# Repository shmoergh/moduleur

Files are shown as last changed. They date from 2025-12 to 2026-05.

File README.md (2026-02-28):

# Shmøergh Moduleur

A fully analog, DIY-friendly modular synthesizer system derived from the original [Shmøergh Hog](https://www.shmoergh.com/hog). The instrument is built from discrete modules — oscillators, filters, VCAs, utilities, and a digital Brain — usable either in their default pre-patched configuration or in any Eurorack system.

The project targets builders who want a reproducible, open, and hackable analog instrument. All circuits, PCBs, firmware, and mechanical designs are published here, including schematics, Gerbers, BOMs, and panel files. Each module is self-contained and can be assembled or modified independently.

Moduleur follows standard Eurorack conventions (±12 V rails, reverse polarity protection, 10-pin power, 1 V/oct where applicable). Designs emphasize robustness, available components, and clear signal flow. Simulation files and test notes are included for further study or modification.

This repository reflects ongoing hardware and firmware development, and module revisions may change over time.

Follow progress at [shmoergh.com](https://www.shmoergh.com/moduleur/)

moduleur-bp
moduleur-bp

## Community

Join the [Shmøergh Discord server](https://discord.gg/CAynJwSkaW).

## Building

[Read the build guide &rarr;](https://github.com/shmoergh/moduleur/wiki)

## Modules

- [Power supply](https://github.com/shmoergh/moduleur/tree/main/modules/01-psu)
- [VCO](https://github.com/shmoergh/moduleur/tree/main/modules/02-vco)
- [Mixer + sidechain compressor](https://github.com/shmoergh/moduleur/tree/main/modules/03-sidechain-mixer)
- [VCF](https://github.com/shmoergh/moduleur/tree/main/modules/04-vcf)
- [ADSR & VCA](https://github.com/shmoergh/moduleur/tree/main/modules/05-adsr-vca)
- [Analog Bitcrusher / S&H + LFO + Output](https://github.com/shmoergh/moduleur/tree/main/modules/06-utils-output)
- [Brain](https://github.com/shmoergh/moduleur/tree/main/modules/07-brain)
- [Default patch](https://github.com/shmoergh/moduleur/tree/main/modules/08-default-patch)

## Enclosure

- [Moduleur enclosure by Shmøergh](https://github.com/shmoergh/moduleur/tree/main/enclosure)
- [Eurorack frame](https://github.com/shmoergh/moduleur/tree/main/eurorack/frame)
- [Eurorack faceplates](https://github.com/shmoergh/moduleur/tree/main/eurorack/faceplates)

## Roadmap

We're working on improving modules, and adding firmwares to Brain as we go. You can see our loosely held ideas in the [Roadmap](./ROADMAP.md) file.

## Contribution & Bug Reports

Contributions are much appreciated, especially in areas where community experience can improve the reliability and longevity of the system.

[Contributing guidelines](./CONTRIBUTING.md)

## License

Shmøergh Hog Moduleur © 2025

Hardware is licensed under [CC BY-NC 4.0](https://creativecommons.org/licenses/by-nc/4.0/)

Software is licensed under [MIT](https://opensource.org/license/mit).

Font used on PCBs: https://departuremono.com

Simulations made in [CircuitJS](https://www.falstad.com/circuit/circuitjs.html)

## ⚠️ Build Smart

Moduleur is an open-source DIY electronics project intended for experienced builders.

Although it operates from low-voltage DC power, incorrect assembly, wiring, or component selection can result in equipment damage or safety risks.

By building this project, you accept full responsibility for safe assembly and operation.

Please read the full safety notice and disclaimer before proceeding:

👉 [Safety & Intended Use](SAFETY.md)

👉 [Full Disclaimer](DISCLAIMER.md)

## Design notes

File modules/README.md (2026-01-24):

# BEFORE YOU BUILD

👉 Make sure you read the full [build guide](https://github.com/shmoergh/moduleur/wiki) thoroughly before you start building the Moduleur.

# BOM

Each module has a dedicated BOM. We also created a full BOM if you want to order all modules at once:

- [Full BOM](https://docs.google.com/spreadsheets/d/1Qo4ZxYgp-tBQ1XDLqPfu5fhcQhO-8mitsnlWUWIVU-8/edit?usp=sharing) — Contains only the BOM for the modules. For the enclosure, check the [enclosure BOM](https://github.com/shmoergh/moduleur/blob/main/enclosure/enclosure-bom.csv).
- [Mouser cart](https://www.mouser.com/Tools/SavedCart/Share?AccessID=7d2d54395b) — Last update: 24 Jan 2026

---

### Recommended build order

1. [PSU](https://github.com/shmoergh/moduleur/tree/main/modules/01-psu)
2. [VCO](https://github.com/shmoergh/moduleur/tree/main/modules/02-vco)
3. [Mixer & sidechain compressor](https://github.com/shmoergh/moduleur/tree/main/modules/03-sidechain-mixer)
4. [VCF](https://github.com/shmoergh/moduleur/tree/main/modules/04-vcf)
5. [ADSR & VCA](https://github.com/shmoergh/moduleur/tree/main/modules/05-adsr-vca)
6. [Utils + Output](https://github.com/shmoergh/moduleur/tree/main/modules/06-utils-output)
7. [Brain](https://github.com/shmoergh/moduleur/tree/main/modules/07-brain)
8. [Default Patch](https://github.com/shmoergh/moduleur/tree/main/modules/08-default-patch)

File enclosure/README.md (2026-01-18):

# Shmøergh Moduleur / DIY Enclosure

## BOM

See [enclosure-bom.csv](enclosure-bom.csv) for the complete bill of materials.

## Build guide

See [Enclosure build guide &rarr;](https://github.com/shmoergh/moduleur/wiki/Enclosure-design)

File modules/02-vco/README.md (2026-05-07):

# Shmøergh Moduleur / VCO

Eurorack compatible VCO for the Shmøergh Moduleur.

## Features

- Raw saw generator with classic waveshaper circuits. Triangle, saw and square outputs
- Sub oscillator and noise circuit (can be selected with a jumper)
- Pulse width voltage control for square wave
- Precision for about 7 octaves
- Hard sync input
- FM input
- Two temperature compensation options for flexible DIY build (one is THT only)
- Designed from very common electronic components

## Boards

- [Core board](./electronics/core/) — Contains all active circuitry and handles the complete audio, CV, and logic processing for the module.
- [UI board](./electronics/ui/) — Hosts all panel-mounted controls and connectors, providing the physical interface to the module’s Core PCB.

## How to build

[**Follow the build guide &rarr;**](https://github.com/shmoergh/moduleur/wiki)

<br>

## Module specific instructions

### Q3 vs Q4 transistor (J111)

As commented on the Core board, **you only need either Q3 or Q4**: if you got Q4 assembled by JLCPCB then do not solder Q3. The J111 JFET is not a super-common component and sometimes it's out of stock at JLCPCB — to prepare for the potential shortage we added a THT footprint too so you can source and solder it manually easily.



### D4 & D5 diodes

These diodes are supposed to clamp the pulse width modulation signal so that it stays withing audible range. You can skip these, they're here for legacy reasons and will be removed in the next version.

CleanShot 2026-04-26 at 06 59 10@2x

### Temperature compensation

All analog VCOs have a way to compensate temperature drifts. You can read about the background of this in this fantastic series of posts on Xonik.no: [part 1](https://www.xonik.no/theory/vco/expo_converter_1.html), [part 2](https://www.xonik.no/theory/vco/expo_converter_2.html), [part 3](https://www.xonik.no/theory/vco/reference_current.html).

We had quite some trouble in the past finding components for temperature compensation (the classic tempco resistors are almost impossible to obtain). So we designed the Moduleur VCO in a way that there are two ways for temperature compensation, **but you need to build only one of them**.

CleanShot 2025-12-15 at 21 54 36@2x

#### Option 1: Using a PTS120601B100RP100 temperature sensor
The PTS1206 is an SMD component so be prepared with your soldering skills. For this the following resistors and trimmers should be soldered (find these in the KiCAD file):

- R_FB: 91kΩ resistor
- R_W1: 20kΩ multiturn trimmer pot
- R_D1: short (with a piece of wire)
- TH1: do not place component
- R_D2: 6.2kΩ (50PPM) resistor
- R_D3: 4.22Ω (50PPM) resistor
- TH2: PTS120601B100RP100 (https://mou.sr/4g7SsGi) temperature sensor
- R_W2: do not place component

Here's the equivalent network of the temperature compensation if you're using PTS120601B100RP100:

CleanShot 2026-04-26 at 06 47 58@2x

#### Option 2: Using a NTCLE203E3103FB0 NTC thermistor
This is a through hole component, very widely available. For this setup, you need to use the following values/components:

- R_FB: 22kΩ resistor
- R_W1: short (with a piece of wire)
- R_D1: 11kΩ resistor
- TH1: NTCLE203E3103FB0 (https://mou.sr/4nM5nSy)
- R_D2: 27kΩ resistor
- R_D3: 2.7kΩ resistor
- TH2: do not place component
- R_W2: 500Ω trimmer

CleanShot 2026-04-26 at 06 49 45@2x

**Which one should you choose?**
The two setups are almost identical but **option 1** (using the PTS) is a little bit more accurate. If you can solder SMD components and you have a bit more budget then we recommend that option.

**Temperature compensation component help**

To make soldering a bit easier, the alternate names of the temp.co. components are marked on the PCB:



### Tuning

You'll need to tune the wave shapes and the oscillator frequency to be musically in tune.

#### Tuning the wave shapes

First we'll set the correct bias to all waveforms as well as the shape of the triangle wave. There are two trimmers you'll need to use: RV_SAW_BIAS1 ("SAW BIAS" on the Core board silkscreen), and RV_TRI_BIAS1 ("TRI BIAS" on the board.). You'll need an oscilloscope for this.

1. Connect the oscilloscope to the Triangle output. Make sure your oscilloscope is in DC coupling.
2. The triangle is generated from the sawtooth wave. In order to have a nice symmetric triangle you need to adjust the saw bias. Use the SAW BIAS trimmer to adjust the symmetry of the Triangle waveshape (and implicitly the bias of the saw wave).
3. The triangle now should be symmetric but most likely not centered around 0V. To move it on the Y axis, use the TRI BIAS trimmer.

You should be good once the triangle output is:

- A nice triangle
- Oscillates around 0V



#### Frequency tuning

As with all analog VCO you need to go through a tuning process to make sure it tracks with 1V/octave. Here's how:

0. Turn the Octave (main tune) knob all the way down and the Fine tune knob in the middle.
1. Connect a keyboard with CV output to the VCO. We recommend an Arturia Keystep, Beatstep Pro, Korg SQ1 or similar. Or if you have the [Brain module](https://github.com/shmoergh/moduleur/tree/main/modules/07-brain) done, you can use [Le Controlleur](https://github.com/shmoergh/le-controlleur) firmware in MIDI mode and a MIDI keyboard too.
2. Turn HI-FREQ pot all the way down: play a very high pitch note on the keyboard and turn the knob until the pitch stops going down.
3. Play C1 on keyboard. Use the BIAS trimmer to set the frequency to C1 (32.703Hz)
4. Play C4 and use BIAS trimmer to set the frequency to C4 (261.63Hz)
5. Play C1 and use WIDTH trimmer to tune it to 32.703Hz
6. Loop steps 3 + 4
7. When C1 and C4 are in tune, play C7 and use the HI-FREQ trimmer to make up the pitch for higher frequencies.
8. Go back to step 3 & 4 to adjust tuning for lower frequencies, then go to step 6 again, until you get to a reasonable end result.

Note that the VCO is limited to about 7-8 octaves. Beyond that, expect the pitch to drift.

### Normalization

`JP2` and `JP3` jumpers on the UI board connect CV and FM to GND respectively to avoid noise on these inputs. They are used for Eurorack use normalization if needed.

👉 **IMPORTANT:** If you're using the default patch board, DO NOT connect these jumpers otherwise your CV inputs will be tied to GND all the time resulting in pitch CV not working on one or both of the VCOs.

CleanShot 2026-03-30 at 10 14 48@2x

<br>

## License

Open source licensed under [CC BY-NC 4.0](https://creativecommons.org/licenses/by-nc/4.0/).

Feel free to fork, build, and tweak.

[Disclaimer](https://github.com/shmoergh/moduleur/blob/main/DISCLAIMER.md)

## Latest module version

v1.0

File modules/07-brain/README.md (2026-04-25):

# Shmøergh Moduleur / Brain

Brain is a universal digital module for the Shmøergh Moduleur which enables the development of new functions like sequencers, MIDI features, digital voices and synths and whatever comes to mind. The module uses a Raspberry Pi Pico / Pico 2 so all features of the board are available in any language (Micropython, C++, Rust). To speed up development we provide an SDK that makes it easy to use the available pots, buttons, I/O and MIDI.

## FIX LOG

‼️ IF YOU ARE NOT BUILDING FROM THE LATEST PCB REVISION IN THIS REPOSITORY, PLEASE CHECK THE [FIX LOG](FIXLOG.md) (PCB ERRATA) BEFORE STARTING, AS EARLIER REVISIONS MAY CONTAIN ISSUES THAT REQUIRE CORRECTION.

## Features

- Universal digital module based on Raspberry Pi Pico or Pico 2
- Three buttons, one of them with LED
- Two potmeters
- Dedicated MIDI input with input protection
- Six dimmable LED indicators
- Two audio or CV inputs
- Two audio or CV outputs
- One pulse input
- One pulse output
- USB-C connector
- Uses an actual Rpi Pico board under the hood
- Brain SDK for all UI components
- CV voltage output tuner trimmer pot
- Software based AC/DC coupling on audio/CV output
- Separate UI & core PCBs for reusability
- 12HP Eurorack compatible design
- Reverse polarity protection

## Programs

&rarr; [Brain firmwares](https://github.com/shmoergh/brain-firmwares)

## Boards

- [Core board](./electronics/core/) — Contains all active circuitry and handles the complete audio, CV, and logic processing for the module.
- [UI board](./electronics/ui/) — Hosts all panel-mounted controls and connectors, providing the physical interface to the module’s Core PCB.

## How to build

[**Follow the build guide &rarr;**](https://github.com/shmoergh/moduleur/wiki)

<br>

## Module specific instructions

### Soldering the Raspberry Pi Pico board

You can solder the Pico to the Core board directly or using pin headers. If you solder directly then you'll need a very thin USB cable to be able to connect to the original micro USB port of the Pico.

### USB-C connection — EXPERIMENTAL

As it's listed on page 7 of the [Pico data sheet](https://pip-assets.raspberrypi.com/categories/610-raspberry-pi-pico/documents/RP-008307-DS-1-pico-datasheet.pdf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), you can use the test points on the Pico board to connect to its USB, as well as control the BOOTSEL button remotely. This allowed us to add an USB-C connection and a dedicated BOOTSEL button, available without taking the enclosure backplate off.

**To use the external USB-C connector and BOOTSEL button, you'll need to connect the Pico's TP1, TP2, TP3 and TP6 test points to dedicated pins of the USB-C and Bootsel button on the Brain's Core board.**

To do this, you have two options:



**Option 1:**
- Solder the Pico to the Brain Core **using pin headers**. The point is to leave some gap between the Pico and the Brain Core board so that you can lead **wires** through the hole in the center of the Core board to connect up the Pico's TP1, TP2, TP3 and TP6 (BOOTSEL) testpoints:



**Option 2:** You can also use pin headers and sockets to connect the Pico to the Core board — this way you can take replace the Pico board in the future, if you need to for some reason. Make sure you use low profile sockets and matching headers in this case, otherwise if you're building for the Moduleur enclosure, the brain module won't fit the height of the case. (Example [socket](https://mou.sr/48U4sKo) and [header](https://mou.sr/4p6XDd6) — Note: this is UNTESTED)

**Option 3:** Solder the Pico directly to the Core board directly and _solder through_ the dedicated TP1, TP2, TP3 and TP6 plated holes. If you choose this option, make sure you solder the Pico to the bottom side of the Core board like shown here:



⚠️ **NOTE — So far only Option 1 is tested.**

## Calibrating the CV outputs
The DAC outputs of the Brain module directly generate up to 4095 mV. These are amplified to 0–10 V — to match Eurorack voltage ranges — by the U4A and U5A op-amps. Because the output stage isn't built around precision components, every assembled Brain has small differences in gain and offset that need to be tuned out before the CV outputs can be trusted for pitch tracking or anything else that demands accuracy.

**Calibration happens in two stages, in this order:**

### 1. Hardware calibration

Adjusts the trimmers `RV_CV_GAIN1` and `RV_CV_GAIN2` that sets the overall gain of the output stages. The goal is to get roughly 1 V per step across the output range. This is a coarse, mechanical adjustment — turn a screw, watch a multimeter — and you typically only do it once per board (or again after any rework on the output op-amps or trimmers).

Use the [Brain diagnostics firmware](https://github.com/shmoergh/brain-diagnostics) for this. Flash it onto the Brain, press Button A to advance to Test 14 (CV output hardware-trimmer calibration), and follow the procedure in that repo's README. 

### 2. Software calibration

Once the analog gain is roughly right, software calibration compensates for the residual drift of op-amp offsets, DAC non-linearity, and the small per-step error that the trimmer can't reach. The result is a calibration table stored in a reserved sector of the Pico's flash. Firmwares **built on the Brain SDK** can load this table on boot and apply it to their CV outputs.

Use the [Brain CV tuner firmware](https://github.com/shmoergh/brain-cv-tuner) for this. Flash it onto the Brain after hardware calibration is done, follow its README to step through and measure each whole-volt point, and the resulting table gets written on the Pico board. Once that's done, you can flash your real firmware back; the calibration data survives subsequent flashes as long as the firmware uses the Brain SDK and reserves the storage sectors at link time (see the Brain SDK's ["Preserving calibration data"](https://github.com/shmoergh/brain-sdk/blob/main/docs/PRESERVING_CV_CALIBRATION.md) doc to learn more).

The order matters. If you run software calibration first and then turn the hardware trimmer, the software calibration numbers become stale and you'll have to redo them. Always trim the hardware first, then run software calibration on top.

After both stages, the Brain's CV outputs will hit the asked-for voltage to within a fraction of a millivolt across the full range — accurate enough for 1 V/octave pitch tracking and any other CV use you care about.

## Development with Picoprobe

The most efficient and probably the cheapest way to develop firmware for the brain is to use a second Pico board as a debug probe, as described in the [official documentation](https://pip-assets.raspberrypi.com/categories/610-raspberry-pi-pico/documents/RP-008276-DS-1-getting-started-with-pico.pdf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) (from page 17). To connect up the PicoProbe board to the Pico on the Core board you need to solder pin headers to the Pico board's DEBUG connections (SWCLK, GND, SWDIO) and also use the J_DEV1 pin header, which is directly connected to the UART RX and TX on pins 1 and 2. If you're housing the Brain module in the Moduleur enclosure we recommend (1) using right angle pin headers and (2) soldering the Pico board's DEBUG headers _oriented to the inside_ of the board, so it fits the space:

picoprobe

<br>

## Firmware development with the Brain SDK

The Brain SDK is a firmware and library collection for the Raspberry Pi Pico/Pico 2, designed to speed up the development. It provides reusable components for I/O, UI, DSP, and more, along with example programs and scripts to streamline project setup and prototyping.

[Brain SDK](https://github.com/shmoergh/brain-sdk)

## License

Open source licensed under [CC BY-NC 4.0](https://creativecommons.org/licenses/by-nc/4.0/).

Feel free to fork, build, and tweak.

[Disclaimer](https://github.com/shmoergh/moduleur/blob/main/DISCLAIMER.md)

## Latest module version

v1.1

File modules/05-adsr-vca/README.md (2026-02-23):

# Shmøergh Moduleur / ADSR + VCA

A combined, Eurorack compatible envelope generator and voltage controlled amplifier module for the Shmøergh Moduleur.

## FIX LOG

‼️ IF YOU ARE NOT BUILDING FROM THE LATEST PCB REVISION IN THIS REPOSITORY, PLEASE CHECK THE [FIX LOG](FIXLOG.md) (PCB ERRATA) BEFORE STARTING, AS EARLIER REVISIONS MAY CONTAIN ISSUES THAT REQUIRE CORRECTION.

## Features

- Combines a full ADSR envelope generator and VCA module in one
- Envelope times go up until 10sec (depending on the used pot values)
- The ADSR output can be normalized to the CV of the VCA
- Bias trimmer for VCA to set base amp level
- LED indicator for envelope
- 12HP Eurorack compatible design
- Reverse polarity protections

## Boards

- [Core board](./electronics/core/) — Contains all active circuitry and handles the complete audio, CV, and logic processing for the module.
- [UI board](./electronics/ui/) — Hosts all panel-mounted controls and connectors, providing the physical interface to the module’s Core PCB.

## How to build

[**Follow the build guide &rarr;**](https://github.com/shmoergh/moduleur/wiki)

<br>

## Module specific instructions

### Setting the envelope output voltage

You can set the [maximum] output voltage of the envelope using the RV_OUT_GAIN1 trimmer on the Core board. Recommended value is 8V.

### Setting the base volume of the VCA

1. Plug in a VCO to the VCA input
2. Connect the output of the VCA to an oscilloscope. Alternatively you can also connect it to the input of the Output module
3. Use the RV_VCA_BIAS2 trimmer to set turn down the volume of the VCA just so that there's nothing on the output. This will make the VCA work in a way that even the smallest control voltages will cause audible gain increase without any crosstalk.

### What if I have crosstalk?

It's likely that you need to turn down the base volume of the VCA using the RV_VCA_BIAS2 trimmer on the Core board.

### Defaulting the ADSR output to VCA CV input

It's a very common way to use an ADSR together with a VCA. To save on cables you can default the ADSR's output to the VCA's CV input by shorting the JP_DEFAULT_ENV_TO_VCA1 jumper.

### R1 resistor should be a short

As marked in the schematics, in the current version the R1 resistor is included for testing/experimental purposes only. You need to short this connection:



## License

Open source licensed under [CC BY-NC 4.0](https://creativecommons.org/licenses/by-nc/4.0/).

Feel free to fork, build, and tweak.

[Disclaimer](https://github.com/shmoergh/moduleur/blob/main/DISCLAIMER.md)

## Latest module version

v1.2

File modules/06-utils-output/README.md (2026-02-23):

# Shmøergh Moduleur / Utils & Output

Combined analog bitcrusher, LFO and an output interface with overdrive in a single Eurorack compatible module.

## FIX LOG

‼️ IF YOU ARE NOT BUILDING FROM THE LATEST PCB REVISION IN THIS REPOSITORY, PLEASE CHECK THE [FIX LOG](FIXLOG.md) (PCB ERRATA) BEFORE STARTING, AS EARLIER REVISIONS MAY CONTAIN ISSUES THAT REQUIRE CORRECTION.

## Features

- Analog bitcrusher
- External trigger of analog bitcrusher, which allows sample & hold usage
- Analog LFO with square and triangle output
- LFO works from about 0.1Hz to 200Hz audio range
- LED indicator for LFO
- Output module to interface line level audio
- LED based overdrive in output module
- Optional dual-mono headphones output
- 12HP Eurorack compatible design
- Reverse polarity protection

## Boards

- [Core board](./electronics/core/) — Contains all active circuitry and handles the complete audio, CV, and logic processing for the module.
- [UI board](./electronics/ui/) — Hosts all panel-mounted controls and connectors, providing the physical interface to the module’s Core PCB. 

## How to build

[**Follow the build guide &rarr;**](https://github.com/shmoergh/moduleur/wiki)

<br>

## Module specific instructions

### LFO pot value

The range of the LFO depends on the value of the frequency pot. The recommended pot value goes from 200kΩ (higher minimum frequency) to 1M (lower minimum frequency). We recommend using a logarithmic pot so that you have more control on low frequencies. We found the sweet spot by using a 500kΩ pot.

### Setting the minimum LFO frequency

In order to charge the main cap of the LFO you'll need to make sure there's _some_ input current on the integrator (U201B). This is the role of the R206 resistor. The lower the value of this resistor the lower frequencies you can achieve with the LFO. Too low values however can make the output latch, we found the sweet spot at around 220Ω.

### Setting the maximum output level

1. Turn drive all the way down
2. Use RV_LINE_OUT_LVL1 trimmer on the Core board to set the maximum output level. You typically want to set it so that it works well with external gear on line level. [More info about line level values](https://en.wikipedia.org/wiki/Line_level)

### Selecting between line out or headphones out

You can use the main output to connect to line out or headphones out using the JP1 jumper on the Core board.

**⚠️ Use stereo cable on the output if you're using headphones** The output is dual-mono, which means that the right and left channel are connected. If you use a mono cable for the output then you'll esentially ground both output channels.

<br>

## Photos



## License

Open source licensed under [CC BY-NC 4.0](https://creativecommons.org/licenses/by-nc/4.0/).

Feel free to fork, build, and tweak.

[Disclaimer](https://github.com/shmoergh/moduleur/blob/main/DISCLAIMER.md)

## Latest module version

v1.1

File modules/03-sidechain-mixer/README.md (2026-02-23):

# Shmøergh Moduleur / Sidechain Mixer

4 channel Eurorack compatible mixer with sidechain compressor.

## Features

- 4 input audio or CV mixer (DC coupled)
- Channel 4 can be used as the control input for a VCA based sidechain compressor that acts on the output mix. Channel 4 can be individually added to the output mix or can remain silent, while the compressor still operates.
- Gain control for channel 4 which allows to amplify line level signals to Eurorack level, allowing to mix external instruments with Eurorack sound sources
- Dedicated output volume control
- Separate core and UI PCBs for reusability and custom UI builds
- Gerber files for JLCPCB order
- Designed from very common electronic components

## Boards

- [Core board](./electronics/core/) — Contains all active circuitry and handles the complete audio, CV, and logic processing for the module.
- [UI board](./electronics/ui/) — Hosts all panel-mounted controls and connectors, providing the physical interface to the module’s Core PCB.

## How to build

[**Follow the build guide &rarr;**](https://github.com/shmoergh/moduleur/wiki)

<br>

## Module specific instructions

### Core circuit block diagram



**How does it work?**

1. INPUT 1-3 is mixed with a DC coupled mixer. The output is inverted.
2. The output of the INPUT 1-3 mixer goes in the audio input of a VCA.
3. INPUT 4 goes in an amp which enables amplifying the [audio] signal from line level to Eurorack level if needed.
4. The gained INPUT 4 goes in a peak detector
5. The output of the peak detector goes in a subtractor (comparator) circuit. This generates a _negative_ control voltage if the peak volume of the audio signal is above a certain threshold (ie. the peak audio signal goes in the `-` input of the subtractor circuit and the threshold [pot] voltage goes in the `[+]` input).
6. The output of the subtractor is used as the control voltage of the VCA. A diode in reverse polarity makes sure that only negative control voltages are "accepted" on the CV input of the VCA, resulting in gain reduction.
7. The output of the VCA goes in a the (output) inverting mixer. This way INPUT 1-3 is inverted back to normal polarity.
8. In order to be able to use INPUT 4 as a regular channel on the mixer, the [gained] INPUT 4 goes through an inverter and then in the output mixer (which inverts it back to normal polarity). Because the gained INPUT 4 is mixed in the final output mixer you can mix line level things with the Moduleur voices.

Some notes:

### Stereo VS mono jack on INPUT 4

The main use case of the sidechain compressor is to split the output of a drum machine and use it to make the Moduleur "pump". Typically you would want to use a [standard split cable](https://www.amazon.com/Belkin-Speaker-Headphone-Audio-Splitter/dp/B000067RC4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) for this.

You want to consider whether to use mono or stereo Jacks for INPUT 4 (J_IN4 on the UI board).

- Option 1: Mono jack ([PJ398SM](https://www.thonk.co.uk/shop/thonkiconn/)) — This allows you to use the default input of INPUT 4 so you can use it on the default patch PCB. However this means that - because of the physical construction of the jack - you'll ground one of the channels of stereo cables. So if you used a split cable to connect up your stereo drum machine then you'll mute one of the channels.
- Option 2: Stereo jack ([PJ366ST](https://www.thonk.co.uk/shop/3-5mm-jacks/)) – If you use a stereo cable then the above problem goes away. But then you'll not be able to use the default input in your default patch PCB.

### Build one of the Experimental options on the UI board

The current version of the UI circuit allows you to choose from two different setups to control the sidechain ratio. This is marked in an **_Experimental_** block in the schematics:



**Option 1: the gain pot sets the gain of INPUT 4**

It allows you to increase line levels to Eurorack. To build this option:

1. Connect pins 2+3 of JP1 and JP2
2. R1 = 10kΩ resistor
3. R2 = DO NOT SOLDER

**Option 2: the gain pot sets the ratio of the subtractor (comparator) circuit**

This option makes a fix gain for INPUT 4, so you won't be able to amplify line levels on INPUT 4 to Eurorack level. This directly sets the ratio of the comparator/subtractor circuit so it's a bit more direct manipulation of the CV input of the VCA. To build this option:

1. Connect pins 1+2 of JP1 and JP2
2. R2 = short
3. R1 = DO NOT SOLDER

**⚠️ Notes**

- You need to build one from the above options to make the sidechain compressor work.
- Option 1 is the recommended option to build, but feel free to experiment with Option 2 too.
- If you're more interested how the above options work, examine the Core circuit
- **R3 is 20kΩ on the UI board, however we found that simply shorting R2 instead makes the threshold work more reliably (essentially allows absolutely turning off compression)**

### Tuning

**Sidechain compressor attack and release times**

The current version of this module allows you to only set a fixed attack and release time for the compressor. Use the RV_ATTACK1 and RV_RELEASE1 trimmers to set these times.

**VCA bias**

The output of the subtractor/comparator controls the gain reduction of the VCA by a negative voltage. Because of this, you need to bias (ie. preset a gain for) the VCA that amplifies the input signal to it's normal level, essentially making the VCA transparent when there's not gain reduction. Here's how to set the bias:

1. Connect a known voltage source such as a VCO or a DC CV signal to INPUT 1
2. Turn up the INPUT 1 channel volume and the MAIN output volume to maximum
3. Connect a jack to the mixer output
4. Connect a multimeter (if used in a DC CV) or oscilloscope (if you used a VCO) to the output jack
5. Use the RV_BIAS1 trimmer to set the output level to exactly the same as the input level

This makes sure that if there's not sidechain compression, the mixer works transparently (ie. what comes in goes out) 

<br>

## License

Open source licensed under [CC BY-NC 4.0](https://creativecommons.org/licenses/by-nc/4.0/).

Feel free to fork, build, and tweak.

[Disclaimer](https://github.com/shmoergh/moduleur/blob/main/DISCLAIMER.md)

## Latest module version

v1.0

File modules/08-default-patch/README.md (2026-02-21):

# Hog Moduleur / Default Patch

An optional passive PCB which connects the modules of the Shmøergh Moduleur. This essentially creates a default patch which makes the Moduleur playable without patch cables.

## How to Build

[**Follow the build guide &rarr;**](https://www.shmoergh.com/moduleur-build-guide)

<br>

## Module specific instructions

### 🐛 3D model bug in schematics

The current version of the 3D model has two bugs: 

1. It incorrectly uses dual row headers. Single row, **long** pin headers should be used on the BACK side of the PCB so that it can connect to the UI board through the holes on the Core board.
2. The side of the ADSR+VCA1, ADSR+VCA2 and UTILS pin headers are wrong. All pin headers should be soldered on the BACK side of the PCB.



<br>

## License

Open source licensed under [CC BY-NC 4.0](https://creativecommons.org/licenses/by-nc/4.0/).

Feel free to fork, build, and tweak.

[Disclaimer](https://github.com/shmoergh/moduleur/blob/main/DISCLAIMER.md)

## Latest module version

v1.0

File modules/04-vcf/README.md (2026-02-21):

# Shmøergh Moduleur / VCF

Dual mode Eurorack compatible analog multimode diode filter.

## Features

- Classic diode filter with extremely drippy character
- Low pass and high pass filter inputs
- Fine-tunable maximum resonance control — can go smooth to crazy
- Two external CV inputs with logarithmic attenuverters
- Optional EMC shielding to isolate external noise
- Separate core and UI PCBs for reusability and custom UI builds
- Gerber files for JLCPCB order
- Designed from very common electronic components

## Boards

- [Core board](./electronics/core/) — Contains all active circuitry and handles the complete audio, CV, and logic processing for the module.
- [UI board](./electronics/ui/) — Hosts all panel-mounted controls and connectors, providing the physical interface to the module’s Core PCB.

## How to build

[**Follow the build guide &rarr;**](https://github.com/shmoergh/moduleur/wiki)

<br>

## Module specific instructions

### Shielding

Diode-ladder filters are extremely sensitive because they work in a very low voltage range. Any noise coming from the outside world can cause humming and buzzing, especially if the noise source is around the diodes. To overcome this, we highly recommend to put the module in a fully shielded enclosure or case. Additionally we added an optional EMI shield above the diodes using standard Harwin GMI shield clips and shield:



- [Harwin GMI clips](https://mou.sr/44w0zrg) (2x)
- [15x20mm Harwin EMI shield can](https://mou.sr/44pU5KB) (1x)

_Note: we never needed to use the above shielding because the Moduleur is in a fully shielded enclosure. This part of the circuit is a non-tested fallback._

**What if my case is not shielded?**

You can still achieve great shielding by using a grounded copper plate that covers the Core module from the back (essentially a 3th layer in the PCB stack).

### Taming the resonance

The resonance of the filter can be quite heavy. If you want to tame the resonance, crank the reso pot to the max and  use the RV_MAX_RESO1 trimmer on the Core board to set the maximum resonance.

### Balance

The RV_BALANCE1 trimmer might be needed to reduce the low-end hum of the filter. We never really needed it, it's there for safety reasons.

### Setting the curve of CV attenuverters

CV1 and CV2 has two attenuverters on their inputs. You can set the curve of the pots by using different values for certain resistors on the UI board. Recommended values range from 10kΩ (more logarithmic) to 1M (more linear):

- For CV1: R4 & R5
- For CV2: R10 & R11

### Setting the lower limit of cutoff

You can set the lowest control voltage of the Cutoff pot to 0V or -12V using the JP1 jumper. -12V can be cool if you know you'll want to use very strong control voltages, however we still recommend to use 0V.

## License

Open source licensed under [CC BY-NC 4.0](https://creativecommons.org/licenses/by-nc/4.0/).

Feel free to fork, build, and tweak.

[Disclaimer](https://github.com/shmoergh/moduleur/blob/main/DISCLAIMER.md)

## Latest module version

v1.0

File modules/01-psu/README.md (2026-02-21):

# Shmøergh Moduleur / PSU – ±12V Eurorack Power Supply

Eurorack compatible power supply unit for the Shmøergh Moduleur.

## Features

- ±12V power. Works with any of the following Mean Well regulators:
    - [NSD10-12D12](https://mou.sr/3ZpECrS)
    - [DKM10A-12](https://mou.sr/450kLTV)
    - [DKMW20F-12](https://mou.sr/44G5aaH)
    - [DKMW30F-12](https://mou.sr/450gwaT)
- Requires **center positive** 12V DC input
- Built in DC barrel jack input and power switch
- Optional +/- input headers for off-board DC & switch placement. Just make sure you know what you're doing if you're using it.
- Open source hardware

There are two board variations available:

1. [8 output for Eurorack](./electronics/eurorack-8-out/). Designed for small Eurorack cases and standalone synth builds. Output current depends on the regulator used (see above).
2. [4 output for Moduleur enclosure](./electronics/moduleur-enclosure/). Designed for the Shmøergh Moduleur enclosure

## Boards

There's a single board for each version, the boards have only through-hole (THT) components.

## How to build

[**Follow the build guide &rarr;**](https://github.com/shmoergh/moduleur/wiki)

## Module specific instructions

### Orientation guide for the Moduleur enclosure

If you're building for the Moduleur enclosure, you need to solder the power connectors on the _bottom_ side of the PCB (ie. the opposite of where the on/off switch and the DC/DC converter is), with the connector pointing to the large cutout on the PCB:





psu-orientation

### Powering the PSU

Use a center positive 12V DC wall adapter to power the PSU.

### Wired DC input and ON/OFF switch

You can create connect your own ON/OFF switch and DC input components using the +/- terminals on the board. This is useful if you're building a custom enclosure and you want the ON/OFF switch and DC input on the enclosre, remote from the PSU. In this case, don't use the built-in DC jack socket and the ON/OFF button.



## License

Open source licensed under [CC BY-NC 4.0](https://creativecommons.org/licenses/by-nc/4.0/).

Feel free to fork, build, and tweak.

[Disclaimer](https://github.com/shmoergh/moduleur/blob/main/DISCLAIMER.md)

## Latest module version

v1.0

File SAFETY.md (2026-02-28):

# Moduleur – Safety & Intended Use Notice

## Intended Use

The Moduleur is an open-source, DIY modular synthesizer system intended for:

- experienced electronics builders,
- low-voltage electronic experimentation,
- sound synthesis and music production,
- operation in dry, indoor environments.

This repository provides design files, documentation, and build guidance for self-assembly.

The Moduleur is **not a consumer appliance** and is **not a finished commercial product** when built by third parties.

---

## Electrical Safety

The Moduleur is designed to operate exclusively from:

- an external SELV-rated DC power adapter
- recommended: 12V DC, center-positive
- supported input range: 9–36V DC

The device must **never** be connected directly to mains voltage.

Improper power supplies, reversed polarity, incorrect wiring, or modifications may result in:

- equipment damage
- fire hazard
- risk of personal injury

Always verify polarity and voltage before powering the device.

---

## DIY Assembly Responsibility

By using the design files and documentation provided in this repository, you acknowledge that:

- You are responsible for correct assembly.
- You are responsible for proper component selection and sourcing.
- You are responsible for ensuring electrical safety during assembly and operation.
- Incorrect assembly may result in equipment damage or safety hazards.

The authors assume no responsibility for damage resulting from incorrect assembly, modification, misuse, or failure to follow the documentation.

---

## Modification & Derivative Builds

The Moduleur is an open-source project and may be modified.

Any modification, adaptation, or derivative build:

- voids any implied responsibility of the original authors,
- may introduce additional safety risks,
- must comply with applicable local regulations if placed into commercial distribution.

---

## Commercial Distribution

If you manufacture, sell, or distribute a built Moduleur device, you are responsible for:

- compliance with applicable safety regulations,
- CE marking (if applicable),
- EMC compliance,
- product liability obligations in your jurisdiction.

---

## No Warranty

The Moduleur design files, documentation, and related materials are provided "as is", without warranty of any kind, express or implied.

To the maximum extent permitted by applicable law, the authors disclaim all warranties, including but not limited to:

- implied warranties of merchantability,
- fitness for a particular purpose,
- non-infringement,
- accuracy or completeness of documentation.

There is no guarantee that the design files are free from errors, omissions, or defects.

---

## Limitation of Liability

To the maximum extent permitted by applicable law, the authors of the Moduleur project shall not be liable for any direct, indirect, incidental, special, exemplary, or consequential damages arising from the use of the design files, documentation, or derivative builds.

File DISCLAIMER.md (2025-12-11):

# Disclaimer

All electronic projects and designs presented on this web site, or associated web sites should be considered dangerous if not lethal if not used safely. When working on projects based on the designs on this site, use extreme care to ensure that you do not come into contact with mains AC voltages or high voltage DC. If you are not confident about working with mains voltages, or high voltages, or you are not legally allowed to work with mains voltages, or high voltages, you are advised not to attempt work on them. The author, host, and all people associated with these web pages disclaim any liability for damages should anyone be killed or injured while working on these projects, or projects based on these designs, or any other project or design presented on these web pages and any associated web pages. The author, host, and all people associated with these web pages also disclaim any liability for projects, or projects based on these designs, or any other project or design presented on these web pages and any associated web pages when used in such a way as to infringe relevant government regulations and by-laws.

All circuits, schematics, printed circuit board, panel design and associated data published on this site can be used for private use only.

We are not responsible for any errors in the PCB design or the parts list. All responsibility for ordering PCBs, components, and assembly services rests solely with you.

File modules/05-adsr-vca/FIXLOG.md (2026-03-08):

# FIXLOG

This document tracks known issues found in specific PCB revisions and how to correct them.
If you are building from anything other than the latest revision in this repository, review this file before starting your build.

## 🐛 Feb 22, 2026 FIX

**If you ordered the Core board before Feb 22, 2026 you need to apply the following fix manually.** The bug is fixed on the Core boards on Feb 22, 2026.

#### Affected boards
v1.1 (rev 2) and earlier

#### Sympthom
The VCA output is not protected against input currents.

#### Solution
Add a 1kΩ resistor between the output jack and the output connection on the UI board.

1. Cut the VCA OUT trace. It's the trace on the top layer of the UI board, coming from the tip of the J_VCA_OUT1 jack. The safest is to just cut it at the base of the jack. Once cut, check with a multimeter short circuit mode that there's no connection between the jack's tip and the VCA_OUT pin of the J3 header.
2. Solder a 1kΩ resistor between the tip of the J_VCA_OUT1 jack and the VCA_OUT of the J3 header. The jack's tip is accessible from the _bottom_ of the board, while the VCA_OUT pin of the J3 header is accessible on the _top_ of the board, so you'll need to use some **insulated wire** to get from the jack to the header.



## 🐛 Dec 30, 2025 FIX

**If you ordered the UI board before Dec 30, 2025 (v1.0 / rev 1) you need to apply the following fix manually.** The bug is fixed for UI boards, ordered after Dec 30, 2025 (specifically [this commit](https://github.com/shmoergh/moduleur/commit/2fd56e93e86553611255dfd17caee376619ceb9c)).

#### Affected boards
v1.0 (rev 1) and earlier

#### Sympthom

The VCA output is "too hot", ie. it is too sensitive to control voltages.

#### Solution

The VCA_CV input needs a 200kΩ resistor from the UI board.

1. On the VCA UI board, cut the VCA CV trace. It's the one coming from TIP of the J_VCA_CV1 jack. Probably the safest place to cut it is at the base of the jack. Once cut, check with a multimeter that there's no connection between the tip of the J_VCA_CV1 and the VCA_CV of the J3 header.



2. Solder a 200kΩ resistor between the tip of J_VCA_CV1 and VCA_CV (of the J3 header)





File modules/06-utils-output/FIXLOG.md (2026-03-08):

## ✨ 16, Jan 2026 IMPROVEMENT

If you ordered the board before 16 Jan 2026 we recommend to add this improvement manually.

**Sympthom:** The LED of the LFO blinks a bit dimmed and gets more dimmed if the LFO is turned all the way up.

**Solution:** Add a 100kΩ feedback resistor between Q1's collector and base (pin 2 & 3) to bias the LFO LED. This makes the LED go very smooth along with the triangle waveshape of the LFO.

CleanShot 2026-01-16 at 09 32 22@2x

CleanShot 2026-01-16 at 09 37 14@2x

Soldering the 100kΩ manually to the Q1 transistor on the back of the UI board (see 3D render above). Note that the module works perfectly without this tweak, it's just an improvement on the LED. This improvement is included in the UI board version v1.1 and above.

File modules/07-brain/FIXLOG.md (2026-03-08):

# FIXLOG

This document tracks known issues found in specific PCB revisions and how to correct them. If you are building from anything other than the latest revision in this repository, review this file before starting your build.

## 🐛 Feb 22, 2026 FIX

**If you ordered the Core board before Feb 22, 2026 you need to apply the above fix.** The is fixed for v1.2 (rev 3) Core boards, ordered after Feb 22, 2026.

#### Affected boards

v1.1 (rev 2) and earlier

#### Sympthom

The pulse output transistor is not protected from large incoming currents.

#### Solution

On the Brain UI board:

1. Cut the trace coming from the TIP of the J_PULSE_OUT1 jack.
2. Solder a 1kΩ resistor between the TIP of J_PULSE_OUT1 jack and the PULSE_OUT pin of the J6 header. For this you'll need insulated wire coming from the back of the board (the jack's tip) to the front of the board (J6 header).



## 🐛 Jan 1, 2026 FIX

**If you ordered the UI board before Jan 01, 2026 you need to apply the above fix.** The is fixed for v1.1 (rev 2) boards, ordered after Jan 1, 2026.

#### Affected boards

v1.0 (rev 1) and earlier

#### Sympthom

The Pulse output couples to the Pulse input resulting in instability of pulse input behavior.

#### Solution

Solder a 10kΩ pull down resistor to the Pulse input jack.







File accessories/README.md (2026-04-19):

# Shmøergh Moduleur Accessories

- [Multiples x Attenuator](./multiples-attenuator/) — combines a 1 -> 4 multiples with 2 attenuators (untested)

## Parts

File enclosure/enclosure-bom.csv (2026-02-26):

Part | Category | Quantity | Note
Front panel | FR4 | 1 | See in `fr4` folder
Back panel | FR4 | 1 | See in `fr4` folder
Side panel – left | FR4 | 1 | See in `fr4` folder
Side panel – right | FR4 | 1 | See in `fr4` folder
Top-bottom panel block | 3D printed | 2 | See in `3d_print` folder
Corner fixtures – left | 3D printed | 2 | See in `3d_print` folder
Corner fixtures – right | 3D printed | 2 | See in `3d_print` folder
Side fixtures | 3D printed | 2 | See in `3d_print` folder
M4 hex socket screws - L: 8mm | Screw | 10 | https://www.amazon.com/BNUOK-120pcs-Socket-Threads-Spanner/dp/B0DYSRGFXQ?sp_csd=d2lkZ2V0TmFtZT1zcF9hdGY
M3 hex socket screws - L: 8mm | Screw | 60 | https://www.amazon.com/BNUOK-120pcs-Socket-Threads-Spanner/dp/B0DJQGPRPV?sp_csd=d2lkZ2V0TmFtZT1zcF9hdGY
M3 threaded insert for 3D printing — L: 5.7mm - Hole size on parts: 4mm | Threaded insert | 4 | https://www.3djake.com/3djake/threaded-inserts-50-piece-set?sai=9419
M4 threaded insert for 3D printing — L: 8.1mm - Hole size on parts: 5.6mm | Threaded insert | 8 | https://www.3djake.com/cnc-kitchen/threaded-inserts-m4-standard?sai=15448
Rubber feet with M3 screws | Feet | 4 | https://www.hestore.hu/prod_10049775.html?lang=en#
M4 hex nuts - 7mm side-to-side | Nut | 2 | https://www.hestore.hu/prod_10023120.html?lang=en
M3 square nuts - 5x5mm | Nut | 4 | https://www.amazon.com/dp/B0BD2N9KTV?sp_csd=d2lkZ2V0TmFtZT1zcF9ocXBfc2hhcmVk
M3 female threaded hex spacers (standoffs) - 10mm, 5.5mm side-to-side | Spacer | 4 | https://mou.sr/49CxSxb
M3 female threaded hex spacers (standoffs) - 40mm, 5.5mm side-to-side | Spacer | 4 | https://mou.sr/45kA2Pn
3.2mm ring terminal lug | Terminal | 2 | -
Short, min 20 SWG wire | Wire | ~50mm | -
---
[OPTIONAL] 10x40 Bosch Rails - L:253mm | Rail | 2 | https://store.boschrexroth.com/en/hu/p/strut-profile-3842526817

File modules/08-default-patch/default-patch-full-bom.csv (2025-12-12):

Reference | Qty | Value | DNP | Exclude from BOM | Exclude from Board | Footprint | Datasheet | Part No. | Part URL | Vendor
H1,H2,H3,H4 | 4 | MountingHole |  | Excluded from BOM |  | MountingHole:MountingHole_3.2mm_M3 | ~
JP1,JP2,JP3,JP4,JP5,JP6,JP7,JP8,JP9,JP10,JP11,JP12,JP13 | 13 | Jumper_2_Bridged |  |  |  | Jumper:SolderJumper-2_P1.3mm_Bridged_RoundedPad1.0x1.5mm | ~
J_ENV_VCA1,J_ENV_VCA2,J_FILTER1,J_MIXER1,J_UTILS_OUT1 | 5 | Conn_01x06 |  |  |  | Connector_PinHeader_2.54mm:PinHeader_2x06_P2.54mm_Vertical | ~ | 200-MTSW12009TS500 | https://mou.sr/4afsn8k | Mouser
J_VCO1,J_VCO2 | 2 | Conn_01x07 |  |  |  | Connector_PinHeader_2.54mm:PinHeader_2x07_P2.54mm_Vertical | ~ | 200-MTSW12009TS500 | https://mou.sr/4afsn8k | Mouser

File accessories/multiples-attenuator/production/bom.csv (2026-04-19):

Designator | Footprint | Quantity | Value | LCSC Part #
J_IO1, J_IO2, J_IO3, J_IO4 | CUI_SJ1-3554NG | 4 | SJ1-3554NG
RV_LVL1, RV_LVL2 | Potentiometer_Bourns_Single-PTV09A | 2 | 100k
U1 | Gyeszno | 1 | ~

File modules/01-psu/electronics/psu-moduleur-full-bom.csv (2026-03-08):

Reference | Qty | Value | Footprint | Part No. | Part URL | Vendor
D1,D3,D4 | 3 | LED | LED_THT:LED_D3.0mm | 604-WP710A10ID | https://mou.sr/45uKc0N | Mouser
D2 | 1 | 1N5822 | Diode_THT:D_DO-201AD_P15.24mm_Horizontal | 863-1N5822G | https://mou.sr/4bASSnN | Mouser
D5 | 1 | 1.5KE36A | Diode_THT:D_DO-201AE_P15.24mm_Horizontal | 576-1.5KE36A | https://mou.sr/4rCTjnz | Mouser
IC1 | 1 | ISOLATED_DC-DC_CONV | Shmoergh_Custom_Footprints:Converter_DCDC_MeanWell_NSD10_DKMW_THT | 709-NSD10-12D12 | https://mou.sr/3ZpECrS | Mouser
J1 | 1 | Barrel_Jack_Switch | Connector_BarrelJack:BarrelJack_Wuerth_6941xx301002 | 710-694106301002 | https://mou.sr/4a9ckVQ | Mouser
J2,J3,J4,J5 | 4 | Conn_02x08_Odd_Even | Connector_IDC:IDC-Header_2x08_P2.54mm_Horizontal | 710-61201621721 | https://mou.sr/3MHt28J | Mouser
R1,R2,R3 | 3 | 1k | Shmoergh_Custom_Footprints:R_Axial_DIN0207_L6.3mm_D2.5mm_P7.62mm_Horizontal | 303-MF0W4FF1001A10 | https://mou.sr/3ZzOD6G | Mouser
S1 | 1 | PB400EEQR1BLK | Shmoergh_Custom_Footprints:SW_PB400EEQR1BLK | 612-PB400EEQR1BLK | https://mou.sr/3TDv9tV | Mouser

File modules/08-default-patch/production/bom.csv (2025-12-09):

Designator | Footprint | Quantity | Value | LCSC Part #
JP1, JP10, JP11, JP12, JP13, JP2, JP3, JP4, JP5, JP6, JP7, JP8, JP9 | SolderJumper-2_P1.3mm_Bridged_RoundedPad1.0x1.5mm | 13 | Jumper_2_Bridged
J_ENV_VCA1, J_ENV_VCA2, J_FILTER1, J_MIXER1, J_UTILS_OUT1 | PinHeader_2x06_P2.54mm_Vertical | 5 | Conn_01x06
J_VCO1, J_VCO2 | PinHeader_2x07_P2.54mm_Vertical | 2 | Conn_01x07

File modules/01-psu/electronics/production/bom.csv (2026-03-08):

Designator | Footprint | Quantity | Value | LCSC Part #
D1, D3, D4 | LED_D3.0mm | 3 | LED
D2 | D_DO-201AD_P15.24mm_Horizontal | 1 | 1N5822
D5 | D_DO-201AE_P15.24mm_Horizontal | 1 | 1.5KE36A
IC1 | Converter_DCDC_MeanWell_NSD10_DKMW_THT | 1 | ISOLATED_DC-DC_CONV
J1 | BarrelJack_Wuerth_6941xx301002 | 1 | Barrel_Jack_Switch
J2, J3, J4, J5 | IDC-Header_2x08_P2.54mm_Horizontal | 4 | Conn_02x08_Odd_Even
JP1 | SolderJumper-2_P1.3mm_Open_RoundedPad1.0x1.5mm | 1 | Jumper_2_Open
R1, R2, R3 | R_Axial_DIN0207_L6.3mm_D2.5mm_P7.62mm_Horizontal | 3 | 1k
S1 | SW_PB400EEQR1BLK | 1 | PB400EEQR1BLK

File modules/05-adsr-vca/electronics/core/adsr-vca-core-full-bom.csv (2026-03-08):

Reference | Qty | Value | Exclude from BOM | Footprint | LCSC | Mouser Part no. | Part URL | Vendor | CHECKED
C1,C2,C5,C6 | 4 | 100n |  | Capacitor_SMD:C_0603_1608Metric | C14663 |  |  | JLCPCB | YES
C3 | 1 | 10n |  | Capacitor_SMD:C_0603_1608Metric | C57112 |  |  | JLCPCB | YES
C4 | 1 | 10u |  | Capacitor_SMD:CP_Elec_5x5.4 | C30110 |  |  | JLCPCB | YES
C7,C8 | 2 | 47p |  | Capacitor_SMD:C_0603_1608Metric_Pad1.08x0.95mm_HandSolder | C1671 |  |  | JLCPCB | YES
C9,C10 | 2 | 100u |  | Capacitor_SMD:CP_Elec_6.3x7.7 | C2836442 |  |  | JLCPCB | YES
D1,D2,D3 | 3 | 1N4148 |  | Diode_SMD:D_SOD-123 | C81598 |  |  | JLCPCB | YES
D4,D5 | 2 | 1N5817 |  | Diode_SMD:D_SOD-323 | C5190152 |  |  | JLCPCB | YES
H1,H2,H3,H4 | 4 | MountingHole | Excluded from BOM | MountingHole:MountingHole_3.2mm_M3_DIN965_Pad |  |  |  | -
J2,J3,J5,J8 | 4 | Conn_02x03_Odd_Even |  | Connector_PinHeader_2.54mm:PinHeader_2x03_P2.54mm_Vertical |  | 200-TSW10307TD | https://mou.sr/4liCQlU | Mouser | YES
J4 | 1 | Conn_01x06 |  | Connector_PinSocket_2.54mm:PinSocket_1x06_P2.54mm_Vertical |  | 200-SSW10601TMS | https://mou.sr/4puxA0F | Mouser | YES
J6 | 1 | Conn_01x02 |  | Connector_PinHeader_2.54mm:PinHeader_1x02_P2.54mm_Vertical |  | 200-HTSW10207TS | https://mou.sr/3IruU3e | Mouser | YES
J7 | 1 | Conn_02x05_Odd_Even |  | Connector_IDC:IDC-Header_2x05_P2.54mm_Horizontal |  | 571-5103310-1 | https://mou.sr/3GwYxj9 | Mouser | YES
Q1 | 1 | BC857 |  | Package_TO_SOT_SMD:SOT-23 | C20069137 |  |  | JLCPCB | YES
Q3 | 1 | BC847BS |  | Package_TO_SOT_SMD:SOT-363_SC-70-6 | C5380687 |  |  | JLCPCB | YES
R1 | 1 | 22k |  | Resistor_SMD:R_0603_1608Metric | C31850 |  |  | JLCPCB | YES
R2,R4,R9,R15,R17 | 5 | 1k |  | Resistor_SMD:R_0603_1608Metric | C21190 |  |  | JLCPCB | YES
R3,R14 | 2 | 47k |  | Resistor_SMD:R_0603_1608Metric | C25819 |  |  | JLCPCB | YES
R5,R6,R7 | 3 | 1M |  | Resistor_SMD:R_0603_1608Metric | C22935 |  |  | JLCPCB | YES
R8,R18,R22,R24 | 4 | 100k |  | Resistor_SMD:R_0603_1608Metric | C25803 |  |  | JLCPCB | YES
R10,R12,R23,R25,R26 | 5 | 10k |  | Resistor_SMD:R_0603_1608Metric | C25804 |  |  | JLCPCB | YES
R11 | 1 | 4.7k |  | Resistor_SMD:R_0603_1608Metric | C23162 |  |  | JLCPCB | YES
R13 | 1 | 15k |  | Resistor_SMD:R_0603_1608Metric | C22809 |  |  | JLCPCB | YES
R20 | 1 | 220 |  | Resistor_SMD:R_0603_1608Metric | C22962 |  |  | JLCPCB | YES
R21 | 1 | 33k |  | Resistor_SMD:R_0603_1608Metric | C4216 |  |  | JLCPCB | YES
R27,R28 | 2 | 470k |  | Resistor_SMD:R_0603_1608Metric | C23178 |  |  | JLCPCB | YES
R29 | 1 | 200k |  | Resistor_SMD:R_0603_1608Metric | C25811 |  |  | JLCPCB | YES
RV_COMP1 | 1 | 10k |  | Potentiometer_THT:Potentiometer_ACP_CA6-H2,5_Horizontal |  | 774-06TR4AA103CP | https://mou.sr/44pTlq5 | Mouser | YES
RV_OUT_GAIN1,RV_VCA_BIAS1 | 2 | 100k |  | Potentiometer_THT:Potentiometer_ACP_CA6-H2,5_Horizontal |  | 774-06TR4AA104CP | https://mou.sr/4oMQfnb | Mouser | YES
U1 | 1 | LM324 |  | Package_SO:SOIC-14_3.9x8.7mm_P1.27mm | C71035 |  |  | JLCPCB | YES
U2 | 1 | TL072 |  | Package_SO:SOIC-8_3.9x4.9mm_P1.27mm | C6961 |  |  | JLCPCB | YES

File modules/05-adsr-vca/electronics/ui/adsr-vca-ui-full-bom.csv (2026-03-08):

Reference | Qty | Value | DNP | Exclude from BOM | Exclude from Board | Footprint | Datasheet | Part no. | Part URL | Vendor | Note
C1 | 1 | 100nF |  |  |  | Capacitor_THT:C_Rect_L7.2mm_W2.5mm_P5.00mm_FKS2_FKP2_MKS2_MKP2 | ~ | 80-MMK5104J50J01L16 | https://mou.sr/4iTinUl | Mouser
D1 | 1 | Red LED |  |  |  | LED_THT:LED_D3.0mm | ~
J1,J3,J6,J8 | 4 | Conn_02x03_Odd_Even |  |  |  | Connector_PinSocket_2.54mm:PinSocket_2x03_P2.54mm_Vertical | ~ | 200-SSW10301TD | https://mou.sr/3GIDVEr | Mouser
J4 | 1 | Conn_01x02 |  |  |  | Connector_PinSocket_2.54mm:PinSocket_1x02_P2.54mm_Vertical | ~ | 200-SSW10201TS | https://mou.sr/4lBvdHe | Mouser
J5 | 1 | Conn_01x06 |  |  |  | Connector_PinSocket_2.54mm:PinSocket_1x06_P2.54mm_Vertical | ~ | 200-SSW10601TS | https://mou.sr/4lnf48h | Mouser
JP_DEFAULT_ENV_TO_VCA1 | 1 | Jumper_2_Open |  |  |  | Connector_PinHeader_2.54mm:PinHeader_1x02_P2.54mm_Horizontal | ~ | 200-HTSW10208TSRA | https://mou.sr/4nM6IZz | Mouser
J_ENV_OUT1,J_GATE1,J_VCA_CV1,J_VCA_IN1,J_VCA_OUT1 | 5 | PJ398SM |  |  |  | Shmoergh_Custom_Footprints:Jack_3.5mm_QingPu_WQP-PJ398SM_Vertical_CircularHoles | ~ | PJ398SM | https://www.thonk.co.uk/shop/thonkiconn/ | Thonk
Q1 | 1 | 2N3904 |  |  |  | Package_TO_SOT_THT:TO-92_Inline_Wide | https://www.onsemi.com/pub/Collateral/2N3903-D.PDF | 637-2N3904 | https://mou.sr/4febysZ | Mouser
Q2 | 1 | 2N3906 |  |  |  | Package_TO_SOT_THT:TO-92_Inline_Wide | https://www.onsemi.com/pub/Collateral/2N3906-D.PDF | 637-2N3906 | https://mou.sr/4a8lju1 | Mouser
R1,R6 | 2 | 0 |  |  |  | Shmoergh_Custom_Footprints:R_Axial_DIN0207_L6.3mm_D2.5mm_P7.62mm_Horizontal | ~ | 603-MFR-25FRF52-47K,603-MFR-25FRF52100K | https://mou.sr/3MWzgkZ,https://mou.sr/4hEwI4G | Mouser
R2 | 1 | 47k |  |  |  | Shmoergh_Custom_Footprints:R_Axial_DIN0207_L6.3mm_D2.5mm_P7.62mm_Horizontal | ~ | 603-MFR-25FRF52-47K | https://mou.sr/3MWzgkZ | Mouser
R3 | 1 | 4.7k |  |  |  | Shmoergh_Custom_Footprints:R_Axial_DIN0207_L6.3mm_D2.5mm_P7.62mm_Horizontal | ~ | 603-MFR25SFTF52-4K7 | https://mou.sr/4q072Ei | Mouser
R4 | 1 | 200k |  |  |  | Shmoergh_Custom_Footprints:R_Axial_DIN0207_L6.3mm_D2.5mm_P7.62mm_Horizontal | ~ | 603-MFR-25FRF52200K | https://mou.sr/4soIlUi | Mouser
R5 | 1 | 10k |  |  |  | Shmoergh_Custom_Footprints:R_Axial_DIN0207_L6.3mm_D2.5mm_P7.62mm_Horizontal | ~ | 603-MFR-25FRF5210K | https://mou.sr/4aLzHIM | Mouser
RV_ATTACK1,RV_DECAY1,RV_RELEASE1 | 3 | A200k-1M |  |  |  | Shmoergh_Custom_Footprints:Potentiometer_Bourns_Single-PTV09A | ~ | 652-PTV09A4025FA105 | https://mou.sr/3VpxrOs | Mouser | D-Shaft
RV_SUSTAIN1 | 1 | 10k |  |  |  | PTA4543-2015DPB103:TRIM_PTA4543-2015DPB103 | ~ | 652-PTA4432015CPB103 | https://mou.sr/45PU5oa | Mouser

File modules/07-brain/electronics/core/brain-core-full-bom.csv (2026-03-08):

Reference | Qty | Value | Exclude from BOM | Footprint | LCSC | Mouser Part no. | Part URL | Vendor | CHECKED
C10,C11 | 2 | 22p |  | Capacitor_SMD:C_0603_1608Metric | C1653 |  |  | JLCPCB | YES
C3,C6,C7,C8,C9,C12,C13,C14,C15,C16,C17,C19,C20 | 13 | 100n |  | Capacitor_SMD:C_0603_1608Metric | C14663 |  |  | JLCPCB | YES
C2 | 1 | 330n |  | Capacitor_SMD:C_0603_1608Metric_Pad1.08x0.95mm_HandSolder | C188679 |  |  | JLCPCB | YES
C1 | 1 | 10u |  | Capacitor_SMD:CP_Elec_4x5.4 | C46550410 |  |  | JLCPCB | YES
C18 | 1 | 10u |  | Capacitor_SMD:C_0603_1608Metric | C19702 |  |  | JLCPCB | YES
C4,C5 | 2 | 100u |  | Capacitor_SMD:CP_Elec_6.3x7.7 | C2836442 |  |  | JLCPCB | YES
R6 | 1 | 120 |  | Resistor_SMD:R_0603_1608Metric | C22787 |  |  | JLCPCB | YES
R12,R13,R22,R23,R34,R35 | 6 | 1k |  | Resistor_SMD:R_0603_1608Metric | C21190 |  |  | JLCPCB | YES
R5 | 1 | 2.2k |  | Resistor_SMD:R_0603_1608Metric | C4190 |  |  | JLCPCB | YES
R2,R7 | 2 | 3.3k |  | Resistor_SMD:R_0603_1608Metric | C22978 |  |  | JLCPCB | YES
R36,R37 | 2 | 5.1k |  | Resistor_SMD:R_0603_1608Metric | C23186 |  |  | JLCPCB | YES
R4 | 1 | 7.5k |  | Resistor_SMD:R_0603_1608Metric | C23234 |  |  | JLCPCB | YES
R3 | 1 | 10k |  | Resistor_SMD:R_0603_1608Metric | C25804 |  |  | JLCPCB | YES
RV_CV_GAIN1,RV_CV_GAIN2 | 2 | 10k |  | Potentiometer_THT:Potentiometer_ACP_CA6-H2,5_Horizontal |  | 774-06TR4AA103CP | https://mou.sr/44pTlq5 | Mouser
R28,R29 | 2 | 33k |  | Resistor_SMD:R_0603_1608Metric | C4216 |  |  | JLCPCB | YES
R8,R9 | 2 | 47k |  | Resistor_SMD:R_0603_1608Metric | C25819 |  |  | JLCPCB | YES
R10,R11 | 2 | 62k |  | Resistor_SMD:R_0603_1608Metric | C23221 |  |  | JLCPCB | YES
R1,R14,R15,R16,R17,R18,R19,R20,R21,R24,R26,R30,R31,R32,R33 | 15 | 100k |  | Resistor_SMD:R_0603_1608Metric | C25803 |  |  | JLCPCB | YES
R25,R27 | 2 | 120k |  | Resistor_SMD:R_0603_1608Metric | C25808 |  |  | JLCPCB | YES
D1,D2,D3 | 3 | 1N5817 |  | Diode_SMD:D_SOD-323 | C5190152 |  |  | JLCPCB | YES
U2 | 1 | 6N137 |  | Package_SO:SOP-8_6.605x9.655mm_P2.54mm | C92651 |  |  | JLCPCB | YES
U10 | 1 | 74HC4051 |  | Package_SO:SOIC-16_3.9x9.9mm_P1.27mm | C9386 |  |  | JLCPCB | YES
U7 | 1 | 74HC4053B |  | Package_SO:SOIC-16_3.9x9.9mm_P1.27mm | C5647 |  |  | JLCPCB | YES
D4 | 1 | BAT54 |  | Package_TO_SOT_SMD:SOT-23 | C22466368 |  |  | JLCPCB | YES
D5,D6 | 2 | BAT54S |  | Package_TO_SOT_SMD:SOT-23 | C7420333 |  |  | JLCPCB | YES
J11 | 1 | Conn_01x01 |  | Connector_PinHeader_2.54mm:PinHeader_1x01_P2.54mm_Vertical |  |  |  | Mouser
J5,J9,J10 | 3 | Conn_01x02 |  | Connector_PinHeader_2.54mm:PinHeader_1x02_P2.54mm_Vertical |  | 200-HTSW10207TS | https://mou.sr/3IruU3e | Mouser
J_DEV1 | 1 | Conn_01x02 |  | Connector_PinHeader_2.54mm:PinHeader_1x02_P2.54mm_Horizontal |  | 200-HTSW11008FSRA | https://mou.sr/4avMlMe
J13 | 1 | Conn_01x03 |  | Connector_PinHeader_2.54mm:PinHeader_1x03_P2.54mm_Vertical |  | 200-HTSW10307TS | https://mou.sr/3KZtJcX | Mouser
J2,J3 | 2 | Conn_02x02_Odd_Even |  | Connector_PinHeader_2.54mm:PinHeader_2x02_P2.54mm_Vertical |  | 200-HTSW10207TD | https://mou.sr/3TDBcz9 | Mouser
J1,J4,J8 | 3 | Conn_02x03_Odd_Even |  | Connector_PinHeader_2.54mm:PinHeader_2x03_P2.54mm_Vertical |  | 200-TSW10307TD | https://mou.sr/4liCQlU | Mouser
J6 | 1 | Conn_02x05_Odd_Even |  | Connector_IDC:IDC-Header_2x05_P2.54mm_Horizontal |  | 571-5103310-1 | https://mou.sr/3GwYxj9 | Mouser
J7 | 1 | Conn_02x05_Odd_Even |  | Connector_PinHeader_2.54mm:PinHeader_2x05_P2.54mm_Vertical |  | 200-TSW10507TD | https://mou.sr/40QhDaC | Mouser
U1 | 1 | LM7805_TO220 |  | Package_TO_SOT_THT:TO-220-3_Horizontal_TabDown |  | 926-LM7805CT/NOPB | https://mou.sr/4gwivXu | Mouser
U6 | 1 | MCP4822 |  | Package_SO:SOIC-8_3.9x4.9mm_P1.27mm | C623653 |  |  | JLCPCB | YES
Q1,Q3,Q6,Q7 | 4 | MMBT3904 |  | Package_TO_SOT_SMD:SOT-23 | C20526 |  |  | JLCPCB | YES
H1,H2,H3,H4 | 4 | MountingHole | Excluded from BOM | MountingHole:MountingHole_3.2mm_M3_DIN965_Pad |  |  |  | N/A
U3 | 1 | Pico |  | Module:RaspberryPi_Pico_Common_Unspecified |  | 358-SC0915 | https://mou.sr/49BoTdS | Mouser
SW1 | 1 | SW_SPST |  | Button_Switch_THT:SW_Tactile_SKHH_Angled |  |  | https://www.hestore.hu/prod_10028126.html | Mouser
U4,U5,U8,U9,U11 | 5 | TL072 |  | Package_SO:SOIC-8_3.9x4.9mm_P1.27mm | C6961 |  |  | JLCPCB | YES
J_USB_C_EXTENSION1 | 1 | USB_C_Receptacle_USB2.0_16P |  | Connector_USB:USB_C_Receptacle_HRO_TYPE-C-31-M-12 | C165948 |  |  | JLCPCB | YES

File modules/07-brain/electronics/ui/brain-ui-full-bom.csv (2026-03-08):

Reference | Qty | Value | DNP | Exclude from BOM | Exclude from Board | Footprint | Datasheet | Part no. | Part URL | Vendor | Note
D1,D2,D3,D4,D5,D6 | 6 | LED |  |  |  | LED_THT:LED_D3.0mm | ~
D7 | 1 | 1N4148 |  |  |  | Diode_THT:D_DO-35_SOD27_P7.62mm_Horizontal | https://assets.nexperia.com/documents/data-sheet/1N4148_1N4448.pdf
J1,J5,J8 | 3 | Conn_02x03_Odd_Even |  |  |  | Connector_PinSocket_2.54mm:PinSocket_2x03_P2.54mm_Vertical | ~ | 200-SSW10301TD | https://mou.sr/3GIDVEr | Mouser
J2,J3 | 2 | Conn_01x02 |  |  |  | Connector_PinSocket_2.54mm:PinSocket_1x02_P2.54mm_Vertical | ~ | 200-SSW10201TS | https://mou.sr/4lBvdHe | Mouser
J4,J6 | 2 | Conn_02x02_Odd_Even |  |  |  | Connector_PinSocket_2.54mm:PinSocket_2x02_P2.54mm_Vertical | ~ | 200-SSW10206TD | https://mou.sr/4eSbYqI | Mouser
J7 | 1 | Conn_02x05_Odd_Even |  |  |  | Connector_PinSocket_2.54mm:PinSocket_2x05_P2.54mm_Vertical | ~ | 200-SSW10501TD | https://mou.sr/4lVCZM9 | Mouser
J_AUDIO_CV_IN1,J_AUDIO_CV_IN2,J_AUDIO_CV_OUT1,J_AUDIO_CV_OUT2,J_PULSE_IN1,J_PULSE_OUT1 | 6 | PJ398SM |  |  |  | Shmoergh_Custom_Footprints:Jack_3.5mm_QingPu_WQP-PJ398SM_Vertical_CircularHoles | ~ | PJ398SM | https://www.thonk.co.uk/shop/thonkiconn/ | Thonk
J_MIDI1 | 1 | PJ366ST |  |  |  | Shmoergh_Custom_Footprints:Jack_3.5mm_QingPu_WQP-PJ398SM_Vertical_CircularHoles | ~ | PJ366ST Stereo | https://www.thonk.co.uk/shop/thonkiconn/ | Thonk
Q1,Q2,Q3,Q4,Q5,Q6 | 6 | 2N3904 |  |  |  | Package_TO_SOT_THT:TO-92_Inline_Wide | https://www.onsemi.com/pub/Collateral/2N3903-D.PDF | 637-2N3904 | https://mou.sr/4febysZ | Mouser
R1 | 1 | 1k |  |  |  | Shmoergh_Custom_Footprints:R_Axial_DIN0207_L6.3mm_D2.5mm_P7.62mm_Horizontal | ~ | 603-MFR-25FRE52-1K | https://mou.sr/4afrY5O | Mouser
R2 | 1 | 10k |  |  |  | Shmoergh_Custom_Footprints:R_Axial_DIN0207_L6.3mm_D2.5mm_P7.62mm_Horizontal | ~ | 603-MFR25SFTF52-10K | https://mou.sr/4po4TSn | Mouser
R3,R4,R7,R8,R11,R12 | 6 | 47k |  |  |  | Shmoergh_Custom_Footprints:R_Axial_DIN0207_L6.3mm_D2.5mm_P7.62mm_Horizontal | ~ | 603-MFR-25FRF52-47K | https://mou.sr/3MWzgkZ | Mouser
R5,R6,R9,R10,R13,R14 | 6 | 4.7k |  |  |  | Shmoergh_Custom_Footprints:R_Axial_DIN0207_L6.3mm_D2.5mm_P7.62mm_Horizontal | ~ | 603-MFR25SFTF52-4K7 | https://mou.sr/4q072Ei | Mouser
R15 | 1 | 0 |  |  |  | Shmoergh_Custom_Footprints:R_Axial_DIN0207_L6.3mm_D2.5mm_P7.62mm_Horizontal | ~ | 603-MFR25SFTF52-10K | https://mou.sr/4po4TSn | Mouser
RV_POT1,RV_POT2,RV_POT3 | 3 | 100k |  |  |  | Shmoergh_Custom_Footprints:Potentiometer_Bourns_Single-PTV09A | ~ | 652-PTV09A4025UB104 | https://mou.sr/41lYe2k | Mouser | Knurled Shaft
U_BTN1 | 1 | SW_SPST_Push_LED |  |  |  | Shmoergh_Custom_Footprints:SPST_Circular_Pushbutton_LED |  | 611-D6RLRDF1LFS | https://mou.sr/41W2K7k | Mouser
U_BTN2 | 1 | SW_SPST_Push |  |  |  | Shmoergh_Custom_Footprints:SPST_Circular_Pushbutton_LED |  | 611-D6R90F2LFS | https://mou.sr/3MGXm3a | Mouser

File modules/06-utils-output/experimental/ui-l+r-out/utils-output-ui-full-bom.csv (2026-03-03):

Reference | Qty | Value | DNP | Exclude from BOM | Exclude from Board | Footprint | Datasheet | Part no. | Part URL | Vendor | Note
C1,C2,C3,C4 | 4 | 100n |  |  |  | Capacitor_SMD:C_1206_3216Metric_Pad1.33x1.80mm_HandSolder | ~ |  | https://mou.sr/4rMiUej | Mouser
D1,D2 | 2 | SMAJ5.0CA |  |  |  | Diode_SMD:D_SMA | https://www.littelfuse.com/media?itemid=75e32973-b177-4ee3-a0ff-cedaf1abdb93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
D_DRIVE1,D_LFO1 | 2 | Red LED |  |  |  | LED_THT:LED_D3.0mm | ~
D_DRIVE_FROM_CORE1 | 1 | Red LED |  |  |  | Connector_PinSocket_2.54mm:PinSocket_1x02_P2.54mm_Vertical | ~
J1,J7 | 2 | Conn_02x03_Odd_Even |  |  |  | Connector_PinSocket_2.54mm:PinSocket_2x03_P2.54mm_Vertical | ~ | 200-SSW10301TD | https://mou.sr/3GIDVEr | Mouser
J2 | 1 | Conn_02x04_Odd_Even |  |  |  | Connector_PinSocket_2.54mm:PinSocket_2x04_P2.54mm_Vertical | ~ | 200-SSW10401TD | https://mou.sr/4qqxl75 | Mouser
J3,J8 | 2 | Conn_01x01_Pin |  |  |  | TestPoint:TestPoint_THTPad_D2.0mm_Drill1.0mm | ~
J4 | 1 | Conn_01x02 |  |  |  | Connector_PinSocket_2.54mm:PinSocket_1x02_P2.54mm_Vertical | ~ | 200-SSW10201TS | https://mou.sr/4lBvdHe | Mouser
J5 | 1 | Conn_01x06 |  |  |  | Connector_PinSocket_2.54mm:PinSocket_1x06_P2.54mm_Vertical | ~ | 200-SSW10601TS | https://mou.sr/4lnf48h | Mouser
J6 | 1 | Conn_02x05_Odd_Even |  |  |  | Connector_PinSocket_2.54mm:PinSocket_2x05_P2.54mm_Vertical | ~ | 200-SSW10501TD | https://mou.sr/4lVCZM9 | Mouser
J_CRUSH_IN1,J_CRUSH_OUT1,J_CRUSH_TRIG1,J_LFO_SQR1,J_LFO_TRI1,J_MAIN_IN1 | 6 | PJ398SM |  |  |  | Shmoergh_Custom_Footprints:Jack_3.5mm_QingPu_WQP-PJ398SM_Vertical_CircularHoles | ~ | PJ398SM | https://www.thonk.co.uk/shop/thonkiconn/ | Thonk
J_MAIN_OUT1 | 1 | PJ366ST |  |  |  | Shmoergh_Custom_Footprints:Jack_3.5mm_QingPu_WQP-PJ398SM_Vertical_CircularHoles | ~ | PJ366ST | https://www.thonk.co.uk/shop/3-5mm-jacks/ | Thonk | Stereo jack
Q1 | 1 | 2N3904 |  |  |  | Package_TO_SOT_THT:TO-92_Inline_Wide | https://www.onsemi.com/pub/Collateral/2N3903-D.PDF | 637-2N3904 | https://mou.sr/4febysZ | Mouser
Q2 | 1 | 2N3906 |  |  |  | Package_TO_SOT_THT:TO-92_Inline_Wide | https://www.onsemi.com/pub/Collateral/2N3906-D.PDF | 637-2N3906 | https://mou.sr/4a8lju1 | Mouser
R1 | 1 | 47k |  |  |  | Shmoergh_Custom_Footprints:R_Axial_DIN0207_L6.3mm_D2.5mm_P7.62mm_Horizontal | ~ | 603-MFR-25FRF52-47K | https://mou.sr/3MWzgkZ | Mouser
R2 | 1 | 4.7k |  |  |  | Shmoergh_Custom_Footprints:R_Axial_DIN0207_L6.3mm_D2.5mm_P7.62mm_Horizontal | ~ | 603-MFR25SFTF52-4K7 | https://mou.sr/4q072Ei | Mouser
R3 | 1 | 100k |  |  |  | Shmoergh_Custom_Footprints:R_Axial_DIN0207_L6.3mm_D2.5mm_P7.62mm_Horizontal | ~ | 603-MFR25SFTF52-4K7 | https://mou.sr/4jOVa6s | Mouser
R4,R5,R14,R15 | 4 | 220 |  |  |  | Resistor_SMD:R_1206_3216Metric_Pad1.30x1.75mm_HandSolder | ~ |  | https://mou.sr/4s5FaAl | Mouser
RV_CRUSH1 | 1 | A1M |  |  |  | Shmoergh_Custom_Footprints:Potentiometer_Bourns_Single-PTV09A | ~ | 652-PTV09A4025FA105 | https://mou.sr/3VpxrOs | Mouser | D-Shaft
RV_DRIVE1 | 1 | 100k |  |  |  | Shmoergh_Custom_Footprints:Potentiometer_Bourns_Single-PTV09A | ~ | 652-PTV09A4025UB104 | https://mou.sr/41lYe2k | Mouser | Knurled Shaft
RV_LFO_AMOUNT1 | 1 | A20k |  |  |  | Shmoergh_Custom_Footprints:Potentiometer_Bourns_Dual-PTV112-4 | https://hu.mouser.com/ProductDetail/Bourns/PTV112-4425A-A203?qs=%252B9%2Fcbd0IE0TZlxUEy84P2Q%3D%3D | 652-PTV1124425AA203 | https://mou.sr/3V1fyW7 | Mouser | D-Shaft
RV_LFO_RATE1 | 1 | A500k-1M |  |  |  | Shmoergh_Custom_Footprints:Potentiometer_Bourns_Single-PTV09A | ~ | 652-PTV09A4025FA105 | https://mou.sr/3VpxrOs | Mouser | D-Shaft
RV_MAIN_VOLUME1 | 1 | A10k |  |  |  | Shmoergh_Custom_Footprints:Potentiometer_Bourns_Single-PTV09A | ~ | 652-PTV09A4025FA103 | https://mou.sr/4bCOV0e | Mouser | D-Shaft
U1,U2 | 2 | NE5532 |  |  |  | Package_SO:SOIC-8_3.9x4.9mm_P1.27mm | http://www.ti.com/lit/ds/symlink/ne5532.pdf |  | https://mou.sr/4r7z40S | Mouser

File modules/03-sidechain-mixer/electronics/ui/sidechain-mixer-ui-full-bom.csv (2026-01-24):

Reference | Qty | Value | DNP | Exclude from BOM | Exclude from Board | Footprint | Datasheet | Part no. | Part URL | Vendor | Note
J1 | 1 | Conn_02x03_Odd_Even |  |  |  | Connector_PinSocket_2.54mm:PinSocket_2x03_P2.54mm_Vertical | ~ | 200-SSW10301TD | https://mou.sr/3GIDVEr | Mouser
J2 | 1 | Conn_02x05_Odd_Even |  |  |  | Connector_PinSocket_2.54mm:PinSocket_2x05_P2.54mm_Vertical | ~ | 200-SSW10501TD | https://mou.sr/4lVCZM9 | Mouser
J3,J7 | 2 | Conn_01x04 |  |  |  | Connector_PinSocket_2.54mm:PinSocket_1x04_P2.54mm_Vertical | ~ | 200-SSW10401TMS | https://mou.sr/4kxE3Vr | Mouser
J4 | 1 | Conn_01x02 |  |  |  | Connector_PinSocket_2.54mm:PinSocket_1x02_P2.54mm_Vertical | ~ | 200-SSW10201TS | https://mou.sr/4lBvdHe | Mouser
J5 | 1 | Conn_01x06 |  |  |  | Connector_PinSocket_2.54mm:PinSocket_1x06_P2.54mm_Vertical | ~ | 200-SSW10601TS | https://mou.sr/4lnf48h | Mouser
J_IN1,J_IN2,J_IN3,J_IN4,J_OUT1 | 5 | PJ398SM |  |  |  | Shmoergh_Custom_Footprints:Jack_3.5mm_QingPu_WQP-PJ398SM_Vertical_CircularHoles | ~ | PJ398SM | https://www.thonk.co.uk/shop/thonkiconn/ | Thonk
R1 | 1 | 10k |  |  |  | Shmoergh_Custom_Footprints:R_Axial_DIN0207_L6.3mm_D2.5mm_P7.62mm_Horizontal | ~ | 603-MFR-25FRF5210K | https://mou.sr/4aLzHIM | Mouser
R2 | 1 | 0 |  |  |  | Shmoergh_Custom_Footprints:R_Axial_DIN0207_L6.3mm_D2.5mm_P7.62mm_Horizontal | ~
R3 | 1 | 20k |  |  |  | Shmoergh_Custom_Footprints:R_Axial_DIN0207_L6.3mm_D2.5mm_P7.62mm_Horizontal | ~ | 603-MFR-25FRF5220K | https://mou.sr/3PSKVAZ | Mouser
RV_IN1,RV_IN2,RV_IN3 | 3 | A100k |  |  |  | PTA3043-2010CIA503:TRIM_PTA3043-2010CIA503 | ~ | 652-PTA30432015A104 | https://mou.sr/45jtvn7 | Mouser
RV_IN4,RV_IN4_GAIN1,RV_MAIN_VOL1,RV_THRESHOLD1 | 4 | A100k |  |  |  | Shmoergh_Custom_Footprints:Potentiometer_Bourns_Single-PTV09A | ~ | 652-PTV09A-4025UA104 | https://mou.sr/47O2sTG | Mouser | Knurled Shaft

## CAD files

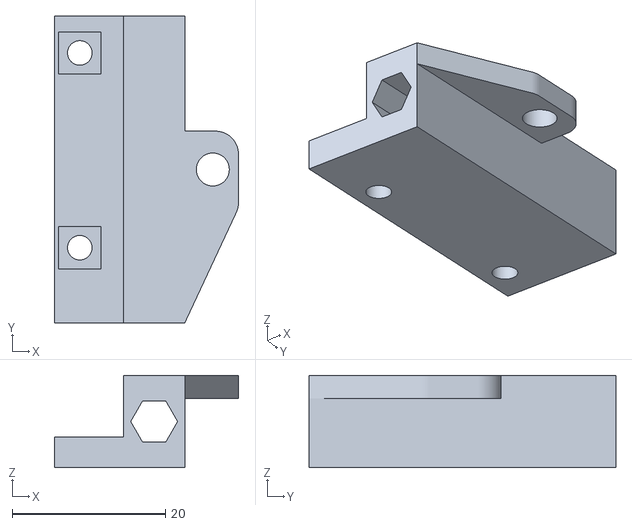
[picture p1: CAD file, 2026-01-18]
enclosure/3d-printed/corner-fixture-left.stl
24.0 x 40.0 x 12.0

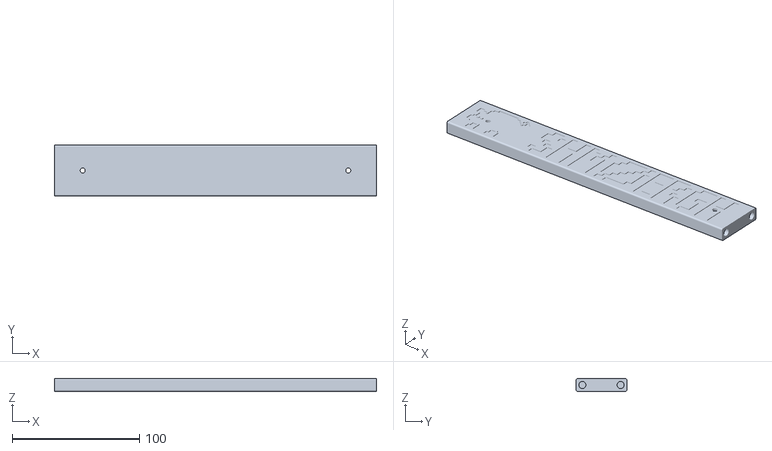
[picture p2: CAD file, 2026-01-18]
enclosure/3d-printed/top-bottom-panel-block.stl
253.0 x 40.0 x 10.0

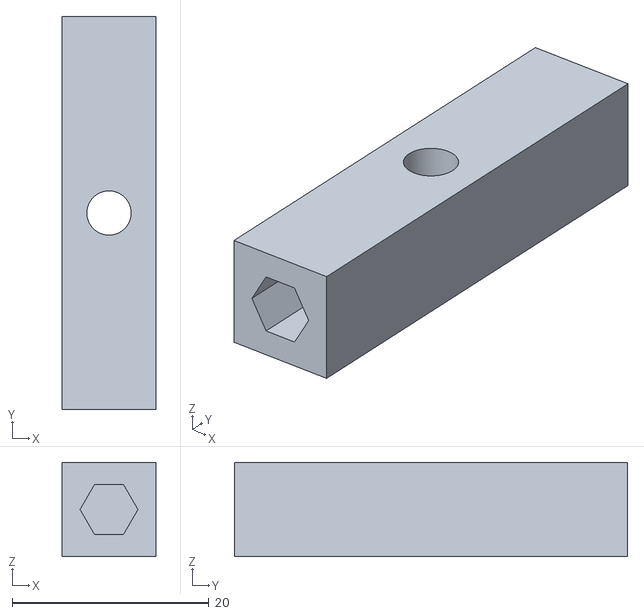
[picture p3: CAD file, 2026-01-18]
enclosure/3d-printed/side-fixture.stl
9.60 x 40.0 x 9.60

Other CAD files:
enclosure/3d-printed/corner-fixture-right.stl

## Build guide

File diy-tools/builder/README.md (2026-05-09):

# Moduleur BOMmap

Soldering companion for the [Moduleur](../../modules) modular synth. Aggregates the iBom files of 8 boards (one rig pass) into a single screen so you can place a given component across all of them at once.

## Layout

The 2×4 minimap matches the physical 8-slot rig:

```
┌─────────┬─────────┬─────────┬─────────┐
│  VCO 1  │  VCO 2  │  Mixer  │   VCF   │
├─────────┼─────────┼─────────┼─────────┤
│ VCA/En1 │ VCA/En2 │  Utils  │  Brain  │
└─────────┴─────────┴─────────┴─────────┘
```

Use the **Core** / **UI** toggle to switch which 8-board pass you're working on.

## Workflow

1. Pick **Core** or **UI**.
2. Browse the aggregated component list on the right. Components are grouped by `value + footprint` and merged across all 8 boards.
3. Click a row → minimap lights up the slots that contain that component, with a per-slot ref count badge. Pick up the part once, place on every highlighted board.
4. Tick the checkbox to mark the row done. Progress is per-pass and persists in `localStorage`.
5. Click a slot to open its full iBom in the centre viewer.

**Keyboard shortcuts:** `1`–`8` switch slots, `C` / `U` switch pass.

## Local dev

```bash
npm install
npm run dev
```

`npm run dev` first runs `scripts/extract-iboms.mjs`, which reads the canonical iBoms from `../../modules/<module>/electronics/<core|ui>/bom/ibom.html`, copies them into `public/iboms/`, and writes the parsed BOM data to `src/data/boards.json`. Re-run `npm run extract` after re-generating any iBom.

## Data flow

```
modules/<module>/electronics/<core|ui>/bom/ibom.html
        │
        ▼  scripts/extract-iboms.mjs (runs LZString.decompressFromBase64)
        │
public/iboms/<module>-<core|ui>.html   (verbatim copy, used by viewer iframe)
src/data/boards.json                   (parsed BOM groups for the React app)
```

## Build & deploy

```bash
npm run build      # extract + tsc -b + vite build → dist/
```

### Vercel

Set the **Root Directory** of the Vercel project to `diy-tools/bommap`. Vercel clones the full monorepo and runs the build inside that subfolder, so `extract-iboms.mjs` can still reach `../../modules/`.

- Build command: `npm run build`
- Output directory: `dist`
- No env vars or runtime needed — pure static.

## Stack

- Vite + React + TypeScript
- Tailwind CSS
- Zustand (`persist` middleware → `localStorage` key `bommap-state`)
- `lz-string` to decompress iBom payloads at build time

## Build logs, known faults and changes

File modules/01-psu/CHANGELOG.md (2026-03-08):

# CHANGELOG

# REV 3

- Minor placement update of R2 to work better with corner blocks of the enclosure. No functional update
- Started using "rev" for board versioning

# v1.1

- Replaced 1N4001 with 1N5822 Schottky diode for overall better performance (faster switch, less temperature dissipation, better surge behavior, ~0.2V voltage drop)
- Added 1.5KE36A TVS at DC jack for ESD protection

# v1.0

- Initial version

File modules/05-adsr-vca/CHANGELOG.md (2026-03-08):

# CHANGELOG

## v1.3

- Added test resistors to VCA output and VCA input

## v1.2

- Added current limiting resistor to VCA output on UI board
- Added LPF on VCA CV for pop-prevention on fast attacks

## v1.1

- Added missing VCA input resistor

## v1.0

- Initial revision

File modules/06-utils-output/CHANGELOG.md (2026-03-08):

# CHANGELOG

## v1.1

- Improves LFO LED behavior

## v1.0

- Initial revision

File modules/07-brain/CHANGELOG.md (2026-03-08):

# CHANGELOG

## v1.3

- Added testing resistor and protection diode to pulse output on UI board
- Updated Mounting Hole H3 to connect to GND so it's not necessary to use wired connection to ground the front and backpanel.

## v1.2

- Added 1k protection resistor to Pulse out on Core board

## v1.1

- Added 10k pull down resistor to Pulse IN on UI board for better stability

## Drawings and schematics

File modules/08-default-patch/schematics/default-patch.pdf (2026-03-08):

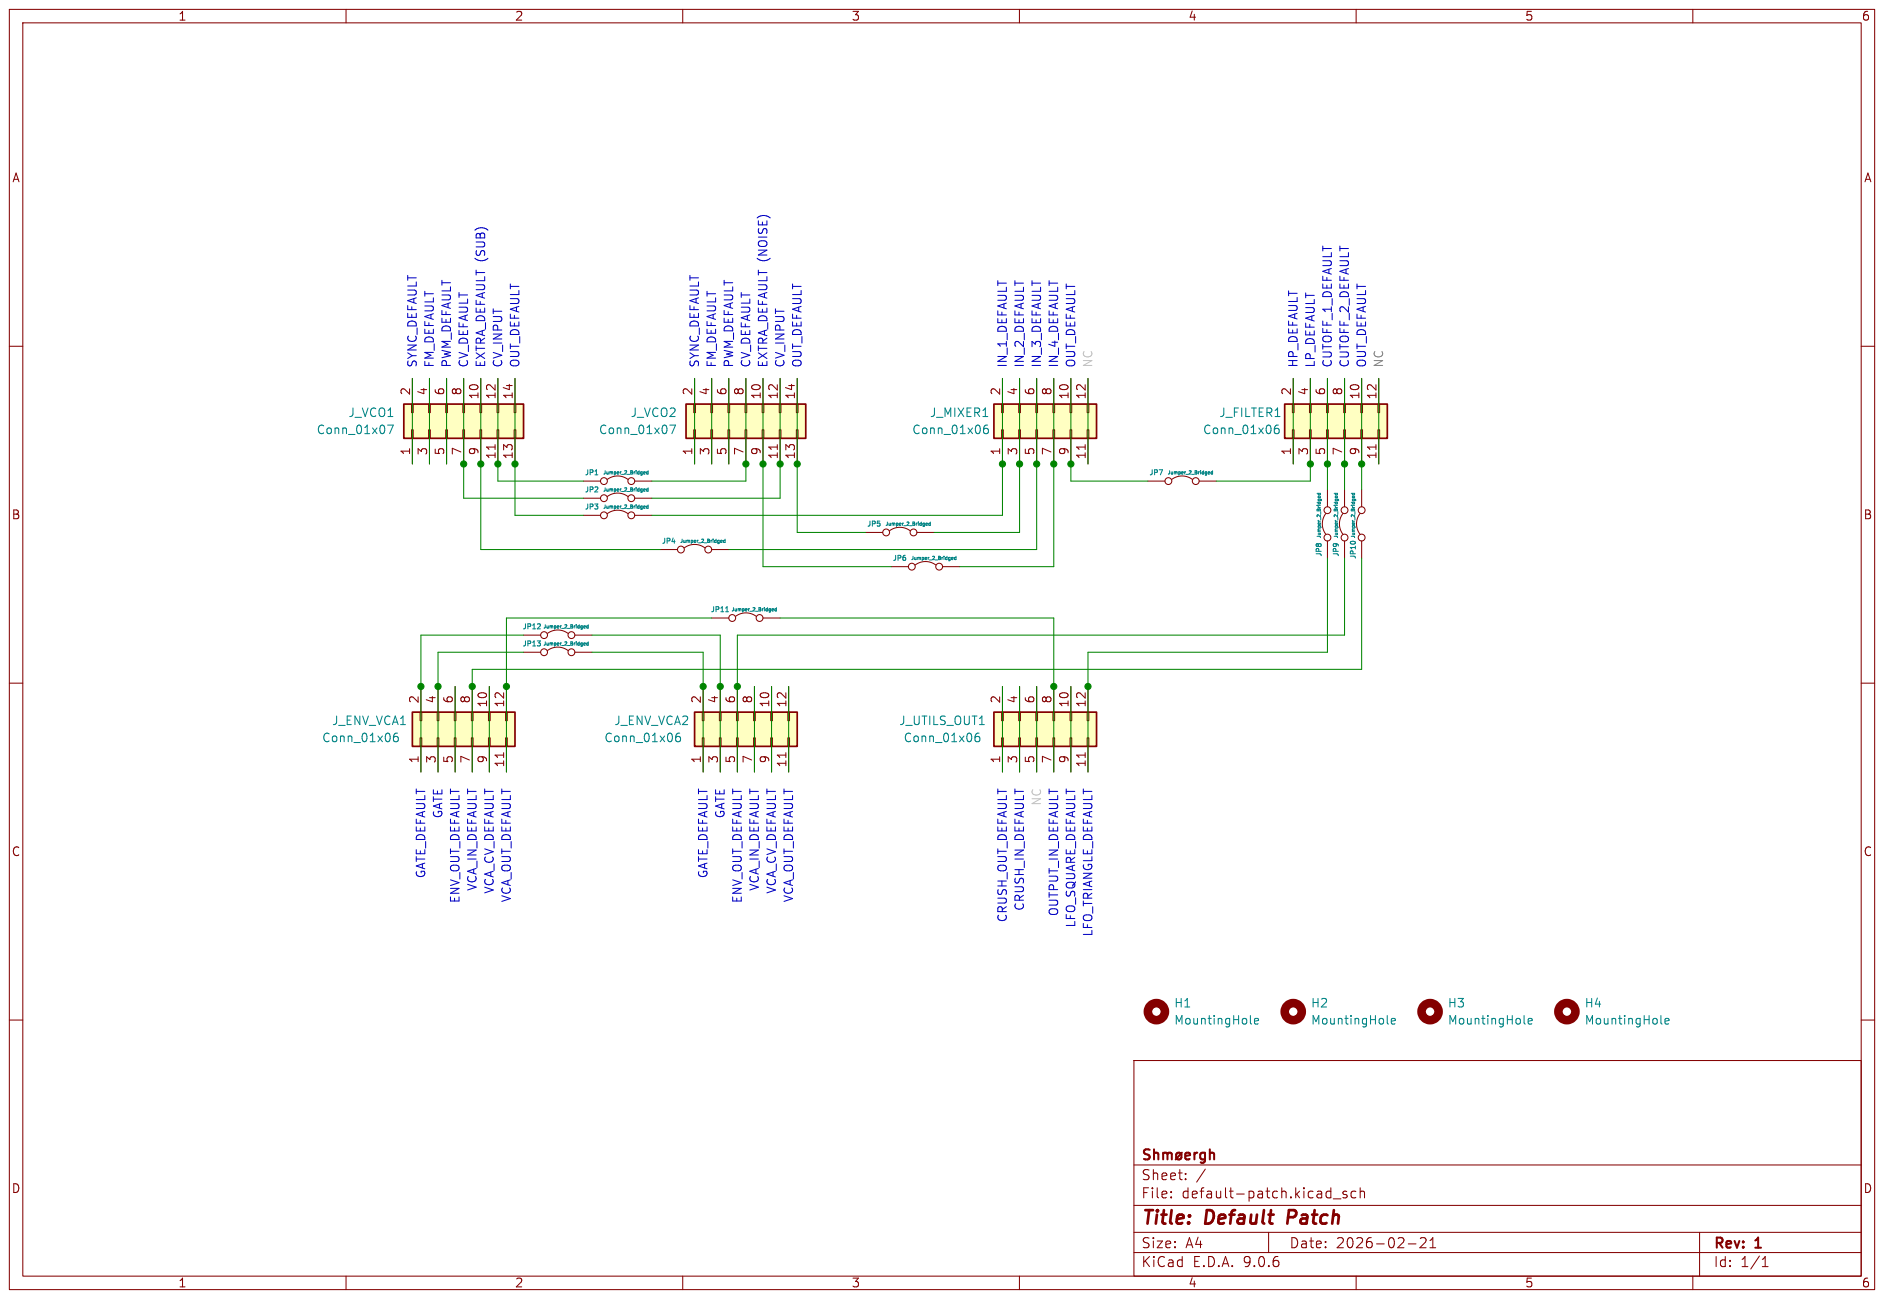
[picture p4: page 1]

File: default-patch.kicad_sch Sheet: / þÿShmøergh

Id: 1/1 Title: Default Patch

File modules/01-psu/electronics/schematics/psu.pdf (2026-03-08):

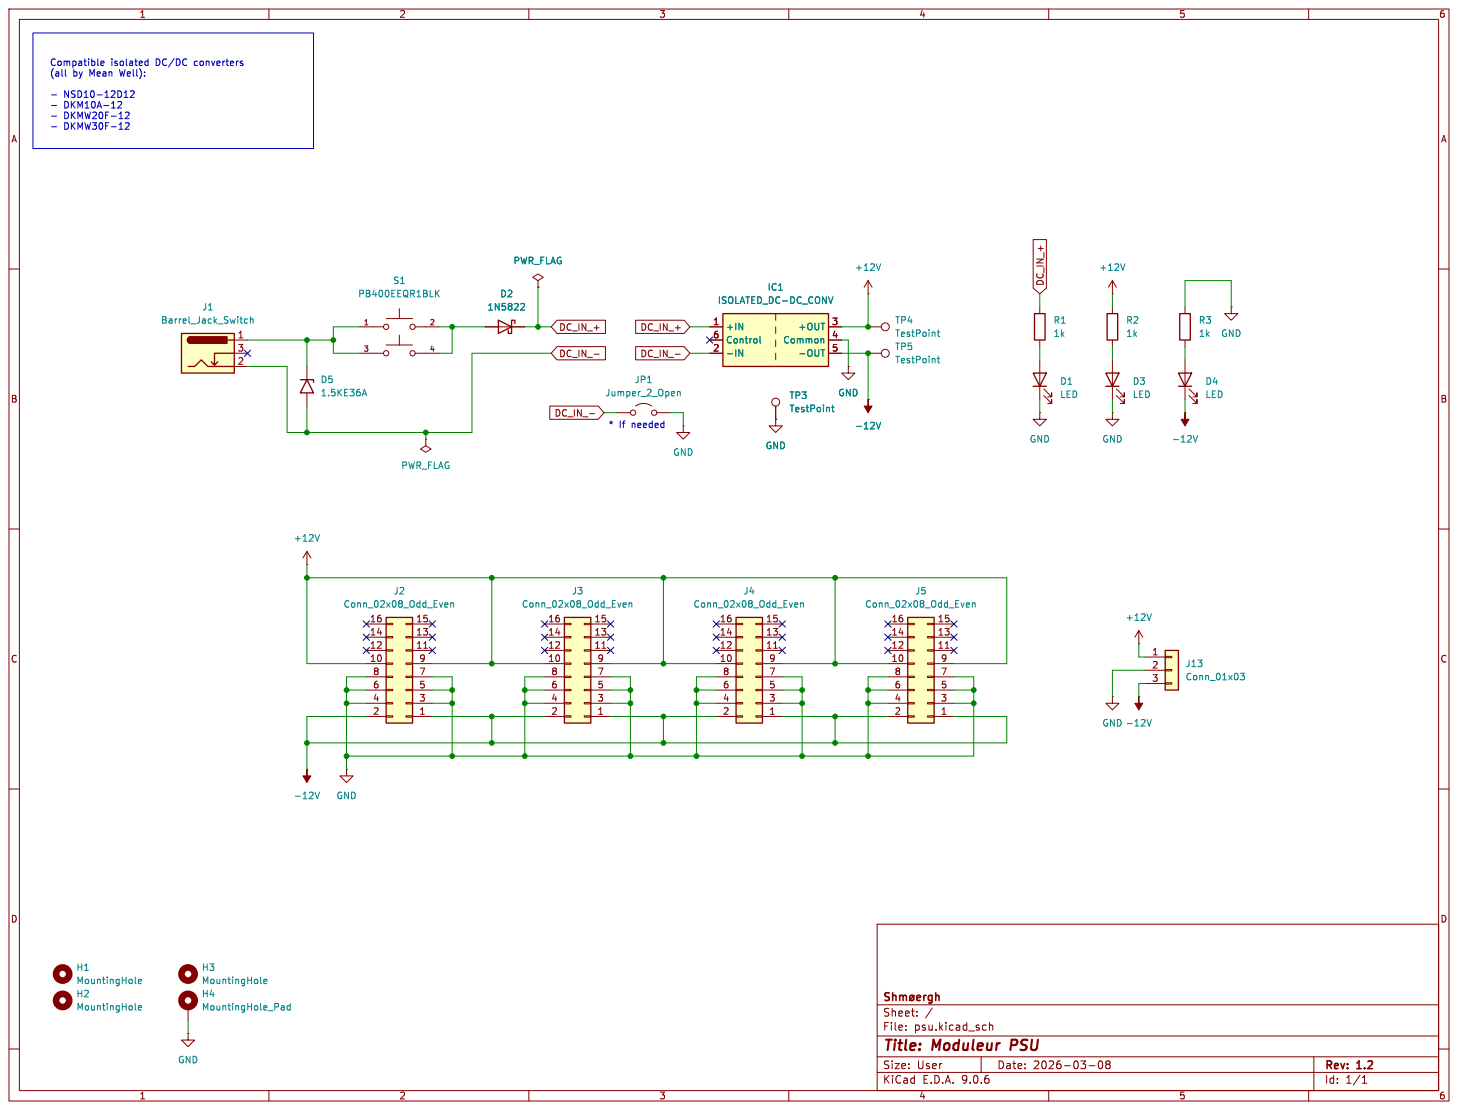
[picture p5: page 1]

(all by Mean Well): - NSD10-12D12

File: psu.kicad_sch Sheet: / þÿShmøergh

Id: 1/1 Title: Moduleur PSU

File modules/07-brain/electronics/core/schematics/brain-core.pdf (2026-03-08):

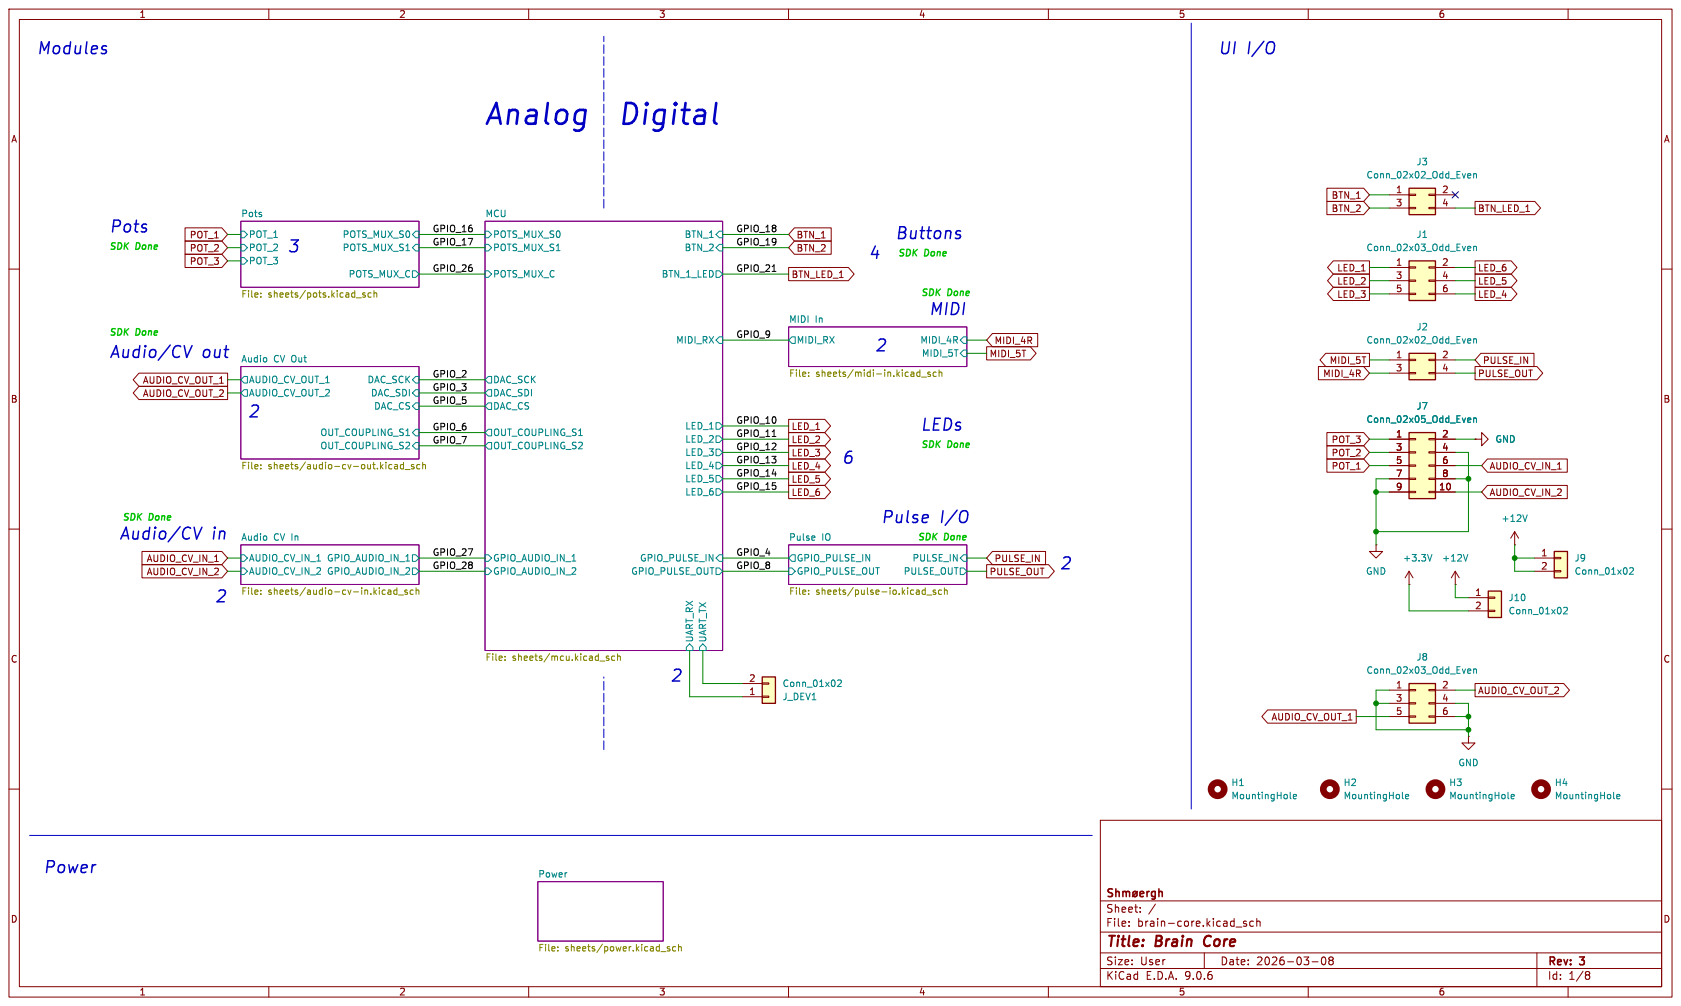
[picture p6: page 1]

Audio/CV out SDK Done Modules

SDK Done MIDI SDK Done LEDs

SDK Done Audio/CV in

File: brain-core.kicad_sch Sheet: / þÿShmøergh

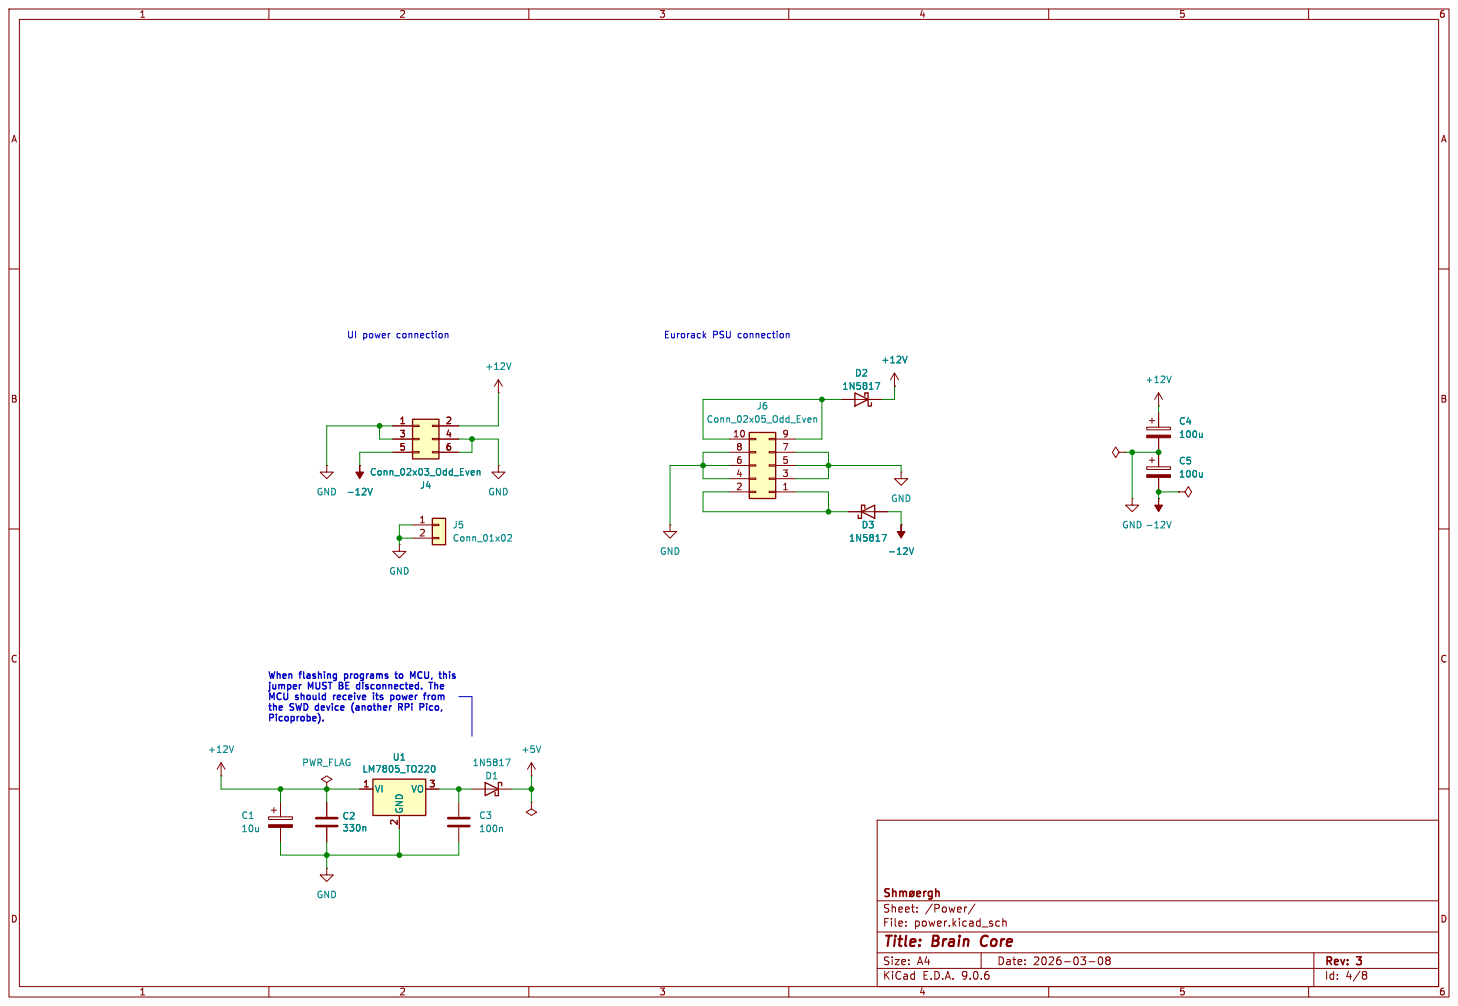
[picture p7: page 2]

100u When flashing programs to MCU, this

File: power.kicad_sch Sheet: /Power/ þÿShmøergh

Id: 4/8 Title: Brain Core

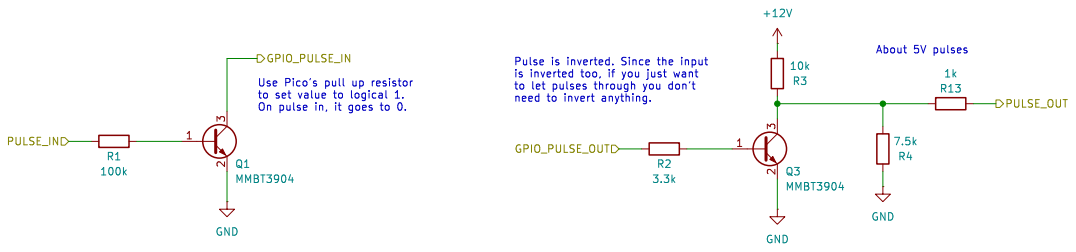
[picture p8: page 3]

is inverted too, if you just want

Id: 5/8 Title: Brain Core

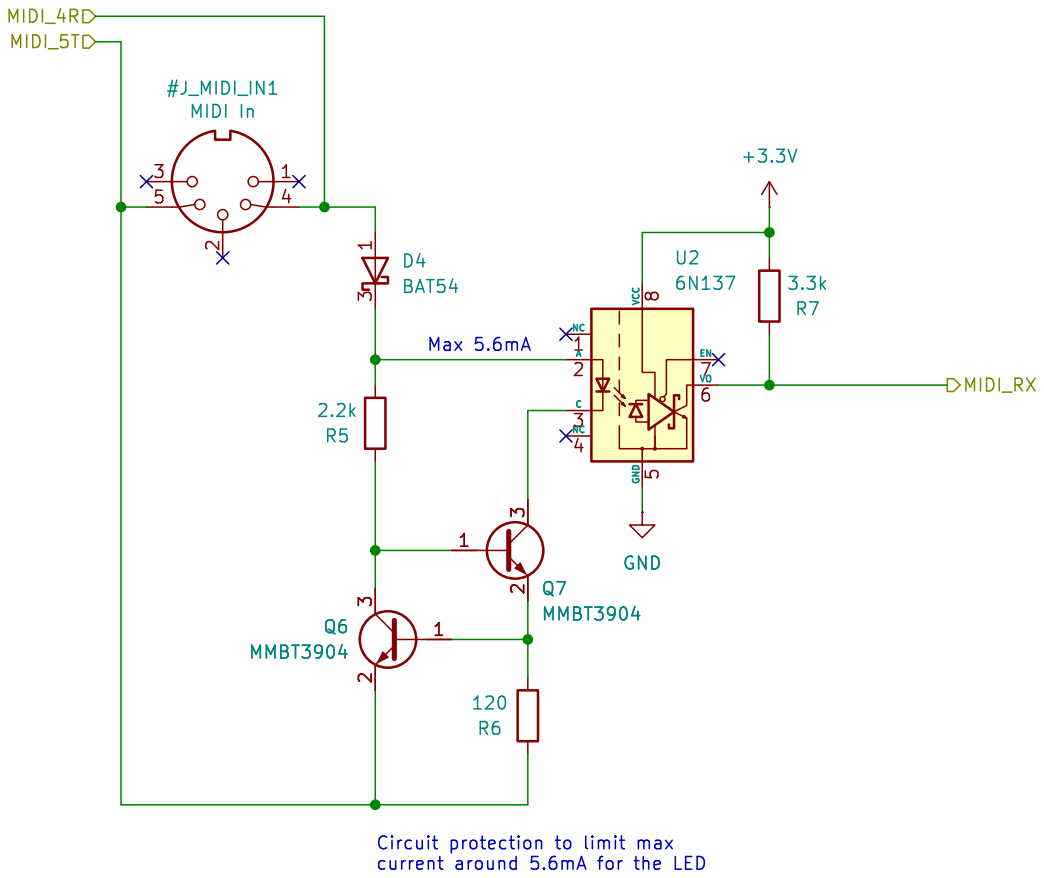
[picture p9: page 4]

current around 5.6mA for the LED GND Q7 MMBT3904

Id: 6/8 Title: Brain Core

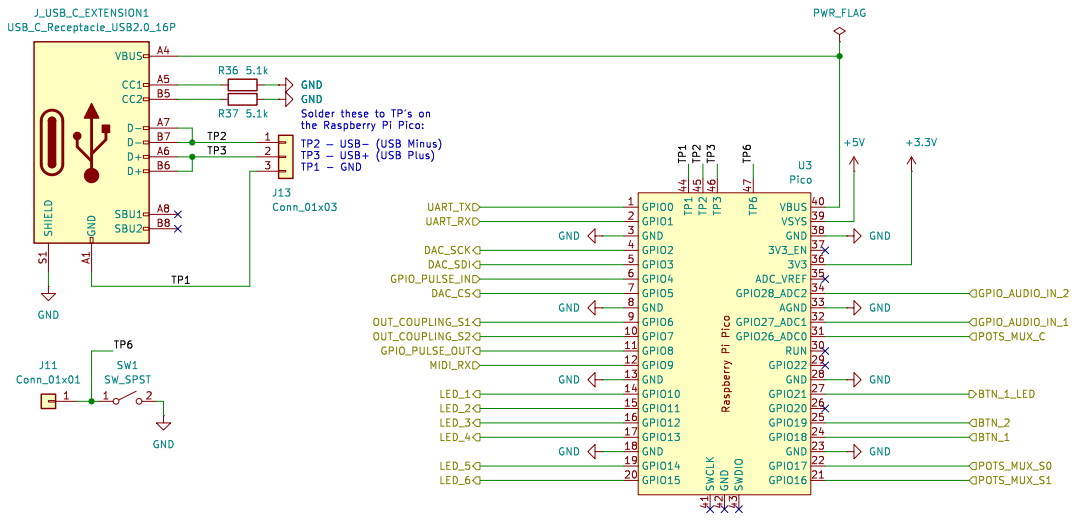
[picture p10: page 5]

the Raspberry Pi Pico: TP2 þÿ  USB-(USB Minus) TP3 þÿ  USB+(USB Plus) TP1 þÿ- GND GND GND

File: mcu.kicad_sch Sheet: /MCU/ þÿShmøergh

Id: 7/8 Title: Brain Core

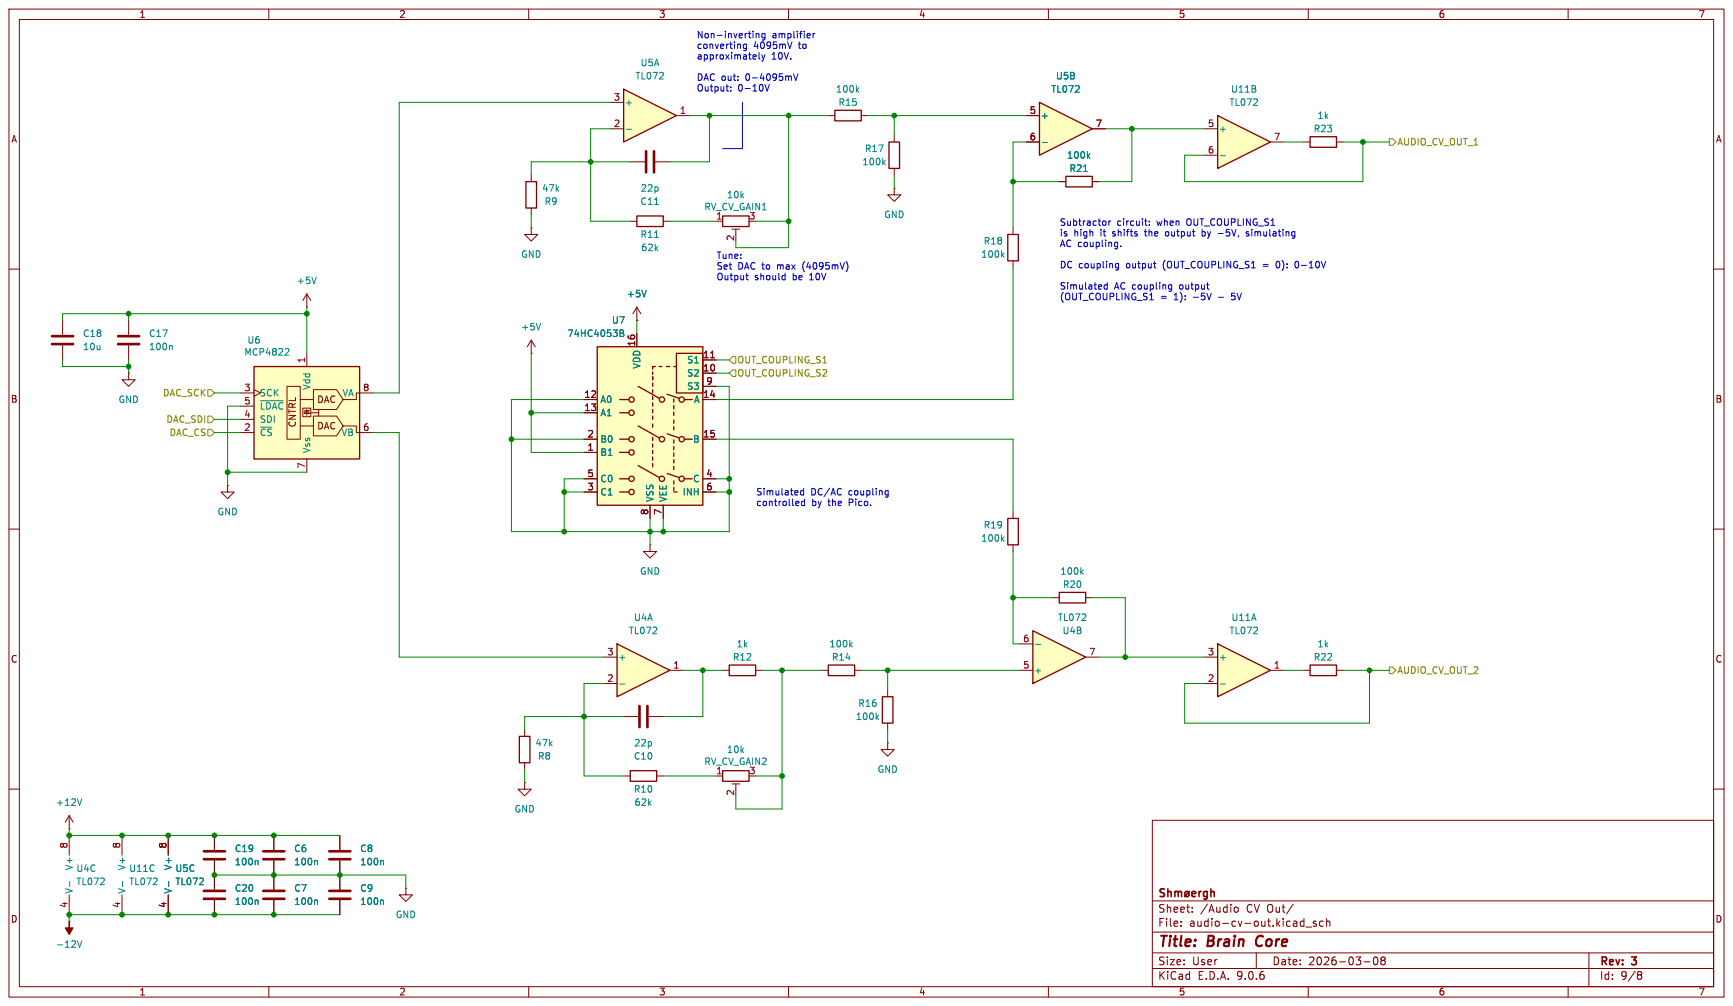
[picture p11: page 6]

Tune: Set DAC to max (4095mV)

Id: 9/8 Title: Brain Core

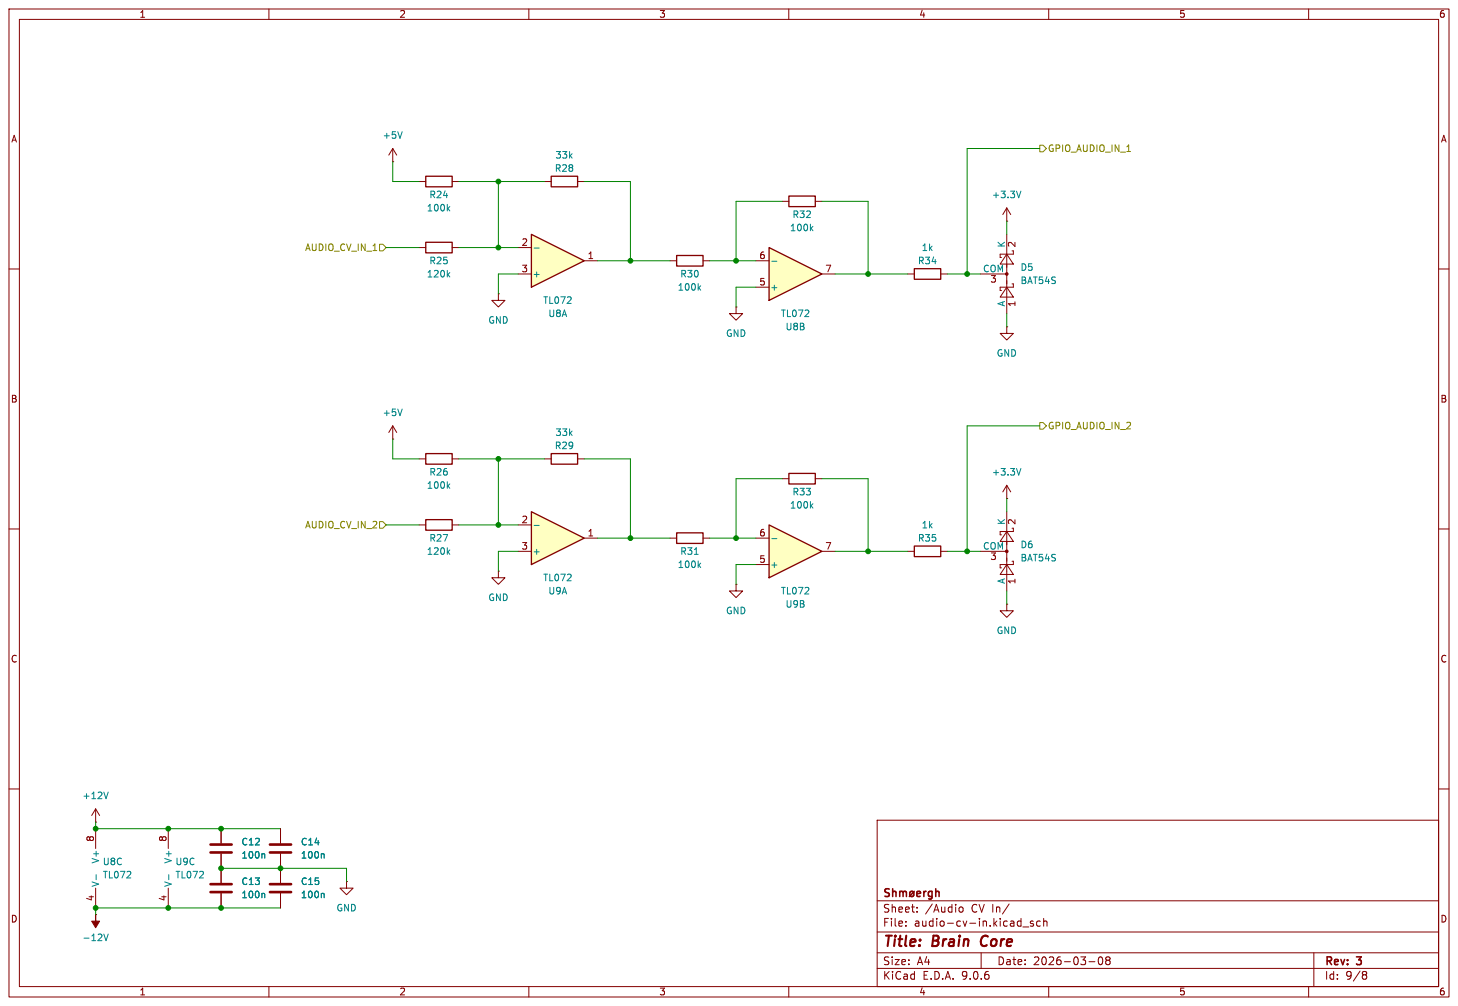
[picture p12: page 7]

Id: 9/8 Title: Brain Core

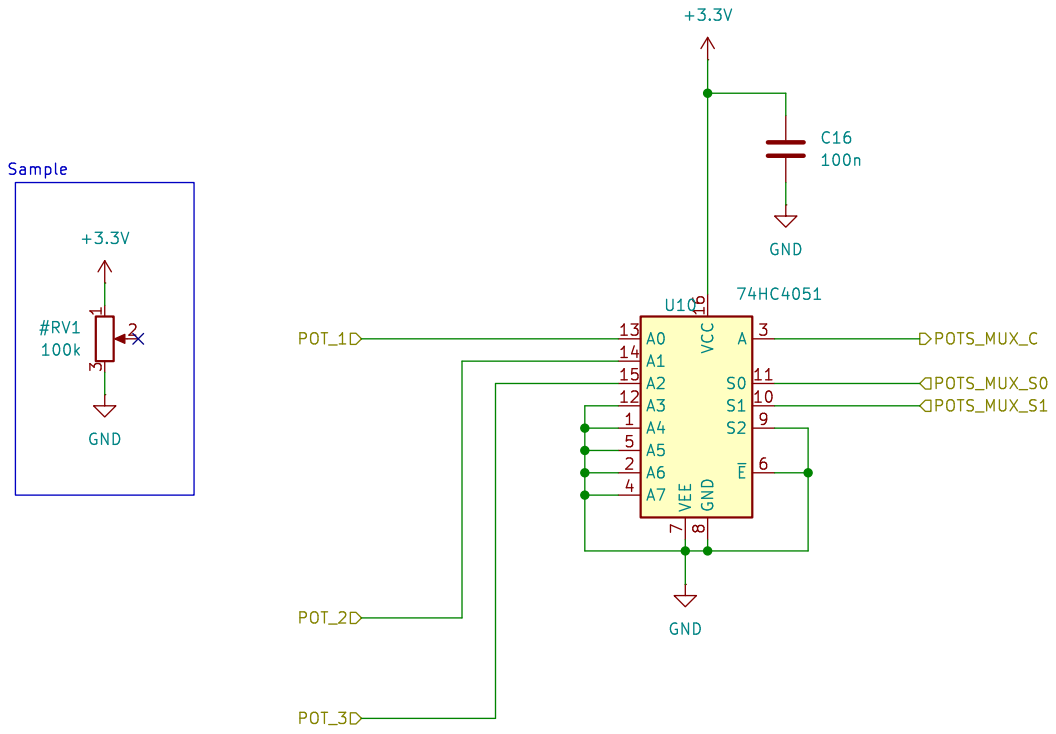
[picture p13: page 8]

File: pots.kicad_sch Sheet: /Pots/ þÿShmøergh

Id: 10/8 Title: Brain Core

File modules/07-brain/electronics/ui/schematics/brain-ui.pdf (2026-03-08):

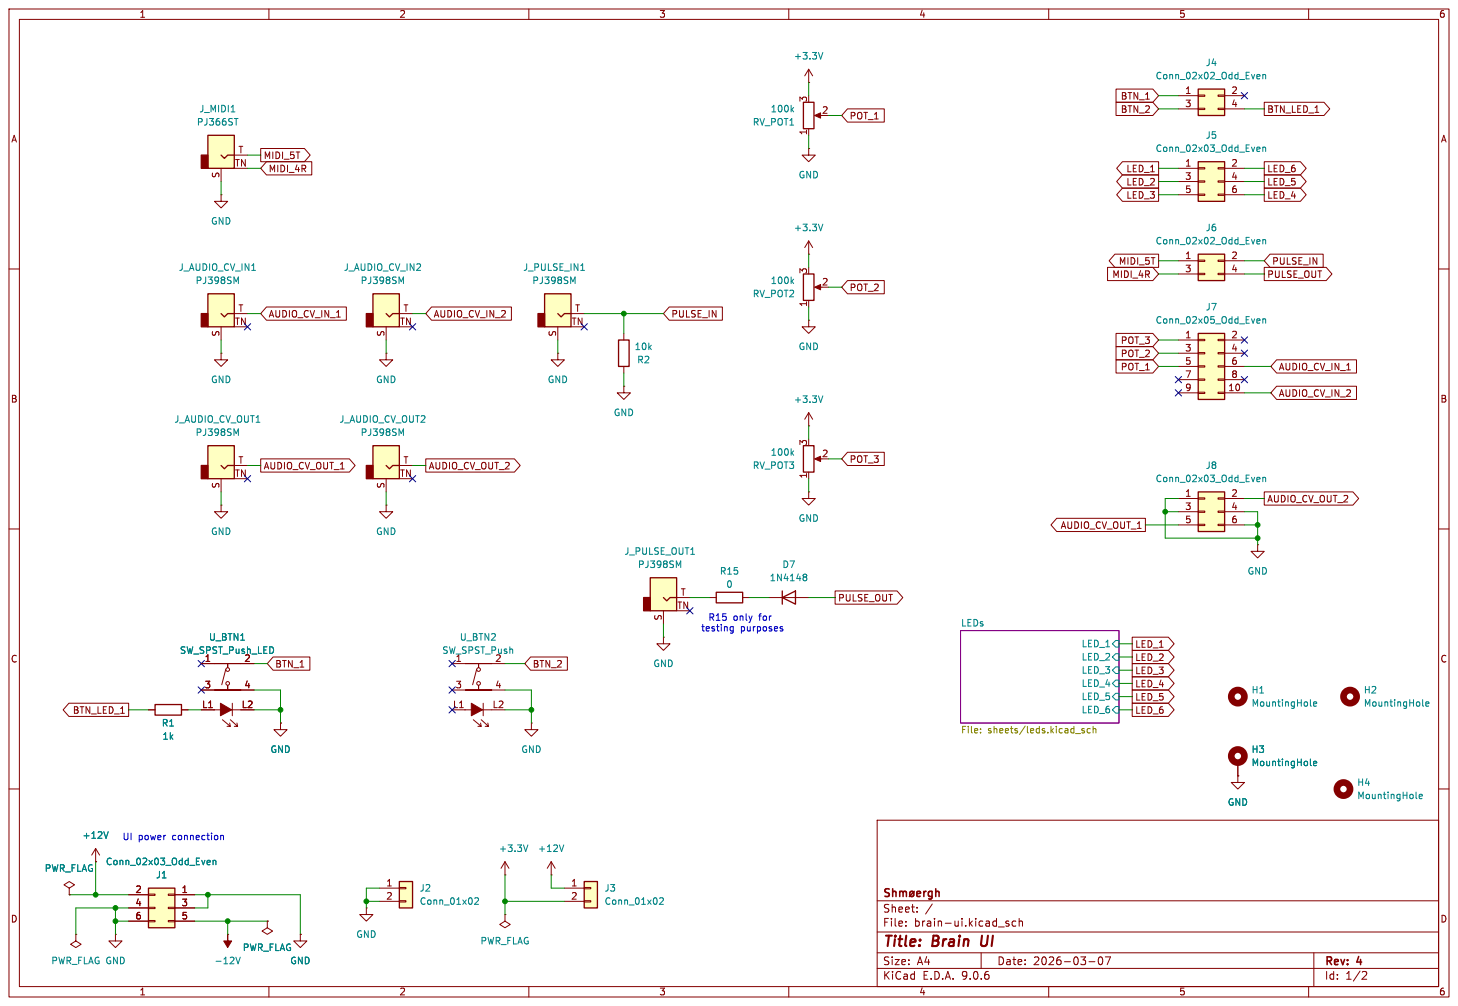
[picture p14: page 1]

LEDs File: sheets/leds.kicad_sch

Id: 1/2 Title: Brain UI File: brain-ui.kicad_sch Sheet: / þÿShmøergh

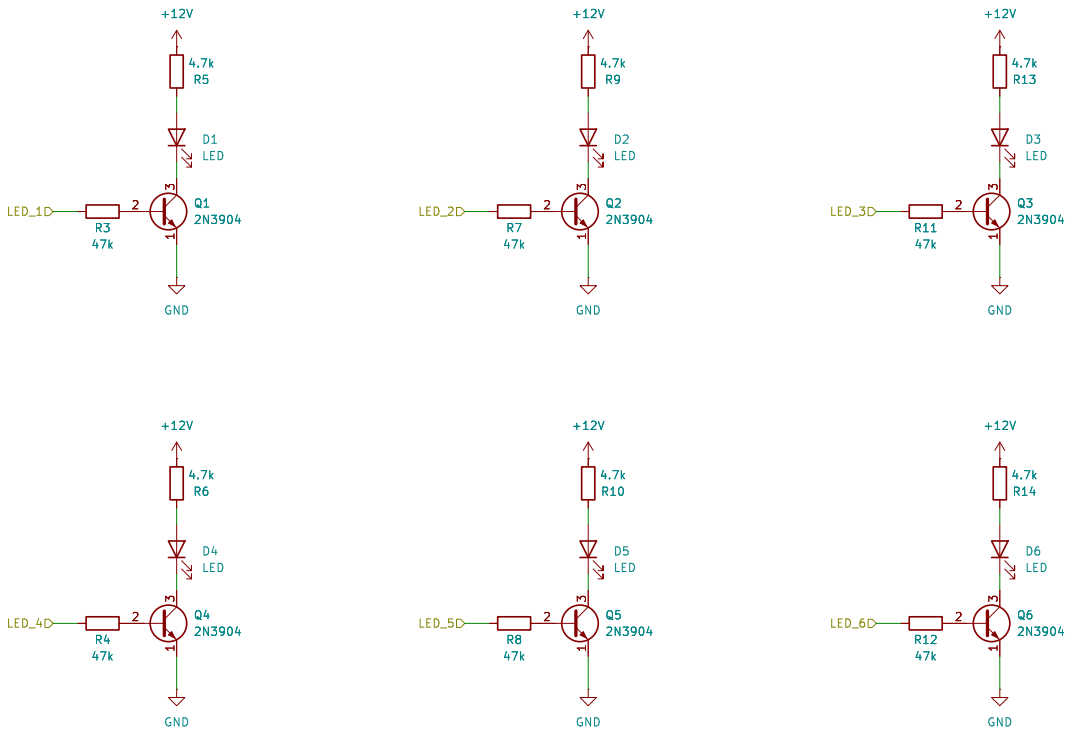
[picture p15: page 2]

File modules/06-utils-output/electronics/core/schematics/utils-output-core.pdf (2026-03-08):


Power File: sheets/power.kicad_sch AUDIO_IN

File: sheets/bitcrusher-sh.kicad_sch

LINE_OUT MAIN_VOL_2 DRIVE_3 MAIN_VOL_3 Output File: sheets/output.kicad_sch

File: utils-output-core.kicad_sch Sheet: / þÿShmøergh

Id: 1/5 Title: Utils / Output Core


S&H notes Aug 20 2025: - tested, works

Id: 3/5 Title: Utils / Output Core


File: lfo.kicad_sch Sheet: /LFO/ þÿShmøergh

Id: 4/5 Title: Utils / Output Core


Id: 4/5 Title: Utils / Output Core


so size should have no effect on output impedance. H

File: output.kicad_sch Sheet: /Output/
Id: 5/5 Title: Utils / Output Core

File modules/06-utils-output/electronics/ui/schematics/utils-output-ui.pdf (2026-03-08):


the LFO rate. 1M felt too much so putting

Dual mono out UI power connection

Id: 1/1 Title: Utils + Output UI File: utils-output-ui.kicad_sch Sheet: / þÿShmøergh GND

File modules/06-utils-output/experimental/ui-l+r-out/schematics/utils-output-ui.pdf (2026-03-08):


the LFO rate. 1M felt too much so putting

J2 Conn_02x04_Odd_Even D_DRIVE1 Red LED GND GND

+12V GND
Dual Headphone File: sheets/dual-headphone.kicad_sch R3


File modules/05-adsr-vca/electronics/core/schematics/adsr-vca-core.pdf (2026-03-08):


File: sheets/vca.kicad_sch Power File: sheets/power.kicad_sch

File: adsr-vca-core.kicad_sch Sheet: / þÿShmøergh CV

Id: 1/4 Title: ADSR + VCA


HOW DOES IT WORK?
together. DECAY_3

to avoid false triggering. 2. C3 is a trigger cap which convers gate to a short pulse

(Attack, Decay, Release) the longer the max times, but also

Id: 3/4 Title: ADSR + VCA


File: vca.kicad_sch Sheet: /VCA/ þÿShmøergh GND

used, so make sure to short one of them. CV inputs can be mixed on the UI board

Id: 4/4 Title: ADSR + VCA


Id: 4/4 Title: ADSR + VCA

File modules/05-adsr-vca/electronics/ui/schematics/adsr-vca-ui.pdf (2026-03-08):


board, R1 and R6 are here for testing

Id: 1/1 Title: ADSR + VCA UI File: adsr-vca-ui.kicad_sch Sheet: / þÿShmøergh

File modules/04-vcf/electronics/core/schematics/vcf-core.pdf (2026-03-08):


Default patch connector Power

Power File: sheets/power.kicad_sch

File: vcf-core.kicad_sch Sheet: / þÿShmøergh

Id: 1/3 Title: Moduleur VCF


0V. If it's too big then it's going to take
longer time which results in the signal going

Usually around 10k This is on

File: vcf.kicad_sch Sheet: /VCF/ þÿShmøergh C15

If you need you can solder a shield around the diodes which is the most noise-prone

part of the circuit.

Id: 3/3 Title: Moduleur VCF


Id: 4/3 Title: Moduleur VCF

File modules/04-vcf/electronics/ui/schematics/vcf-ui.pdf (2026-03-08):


curve of the attenuverter: 10k þÿ logarithmic 1M þÿ close to linear Around 47k is a pretty sweet spot. R4

Id: 1/1 Title: Moduleur VCF UI File: vcf-ui.kicad_sch Sheet: / þÿShmøergh GND

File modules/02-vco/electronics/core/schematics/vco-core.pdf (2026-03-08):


TRI Waveshapers File: sheets/waveshapers.kicad_sch Power File: sheets/power.kicad_sch NOISE

Sub + Noise File: sheets/sub+noise.kicad_sch FM
HARD_SYNC

File: vco-core.kicad_sch Sheet: / þÿShmøergh

Id: 1/5 Title: Moduleur VCO core


1.5k R8See t.comp. table TH2 PTS120602B100RP100 R3 See t.comp. tableC7

be close to each other Set output to C0 with BIAS when

2k (prec) R6 See t.comp. table TH1 See t.comp. table C4

2 R_WIDTH2 See t.comp. table GND

Play a very high pitch note and start turning the trimpot so that the pitch is going down. Once it doesn't go lower

to C4 (261.63Hz) 4. Play C1 and use R_WIDTH to tune it to 32.703Hz) LOOP 3 + 4

5. When C1 and C4 are in tune, play higher octave C's and use R_HIFREQ to adjust tuning for them.

If needed, repeat steps 3 and 4 for other note pairs.

File: raw-oscillator.kicad_sch Sheet: /Raw oscillator/ þÿShmøergh


----------------- Connect any number of CV inputs through input resistors

to set the pulse width with a CV on SQR_SHAPE. Use the

Use bias to set the center of

File: waveshapers.kicad_sch Sheet: /Waveshapers/


File: power.kicad_sch Sheet: /Power/ þÿShmøergh

Id: 4/5 Title: Moduleur VCO core


Id: 5/5 Title: Moduleur VCO core

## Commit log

2025-12-07 Adding enclosure files
    Added all enclosure print and cut files, also a STEP file and made a readme and a readme modification on the top level to fix a link
    [shmoergh-moduleur-panel-assembly-top.step]
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2025-12-08 Eurorack files
    reorganized folder structure, added faceplate files, Readme changes, link changes
    [eurorack-panel-shmoergh-moduleur-brain.step, eurorack-panel-shmoergh-moduleur-crush-lfo-output.step, eurorack-panel-shmoergh-moduleur-envelope-vca.step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]
2025-12-08 Added dxf and lightburn files
    [eurorack-panel-shmoergh-moduleur-brain.dxf, eurorack-panel-shmoergh-moduleur-crush-lfo-output.dxf, eurorack-panel-shmoergh-moduleur-envelope-vca.dxf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]
2025-12-09 Added alternative UI to VCO
    [bom.csv, designators.csv, positions.csv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]
2025-12-09 Added Glided VCO UI PCB
    [vco-ui.kicad_pcb, vco-ui.kicad_sch]
2025-12-09 Added VCA amp bias pot
    [adsr-vca-core.kicad_pcb, adsr-vca-ui.kicad_pcb, adsr-vca-ui.kicad_sch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]
2025-12-09 Updated default patch for noise <> SUB
    [default-patch.kicad_pcb, default-patch.kicad_sch]
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2025-12-09 Reverted VCA to no-bias version
    [adsr-vca-ui.kicad_pcb, adsr-vca-ui.kicad_sch]
2025-12-09 Reverted default patch
    [default-patch.kicad_pcb, default-patch.kicad_sch]
2025-12-09 Reverted current Brain
    [audio-cv-in.kicad_sch, audio-cv-out.kicad_sch, bom.csv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]
2025-12-10 Moved modules into directory + updated lib paths
    [5v-source.kicad_sch, adsr-lm324.kicad_sch, adsr-vca-core.kicad_pcb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]
2025-12-11 Moved folder to branch
    [5v-source.kicad_sch, adsr-lm324.kicad_sch, adsr-vca-core.kicad_pcb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]
2025-12-11 PSU/euro ready for 1.0
    [bom.csv, designators.csv, mouser-bom.csv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]
2025-12-11 PSU/Moduleur ready for v1.0
    [bom.csv, designators.csv, mouser-bom.csv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]
2025-12-11 VCO JLCPCB export done for v1.0
    [bom.csv, positions.csv, power.kicad_sch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]
2025-12-11 Mixer JLCPCB verified for 1.0
    [sc-mixer.kicad_sch, sidechain-mixer-core.kicad_pcb, sidechain-mixer-core.kicad_sch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]
2025-12-11 VCF JLCPCB verified for v1.0
    [bom.csv, designators.csv, positions.csv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]
2025-12-11 ADSR+VCA JLCPCB verified for v1.0
    [adsr-vca-core.kicad_pcb, adsr-vca-core.kicad_sch, bom.csv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]
2025-12-11 ADSR+VCA UI JLCPCB verified for 1.0
    [adsr-vca-ui.kicad_pcb, adsr-vca-ui.kicad_sch, bom.csv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]
2025-12-11 Utils JLCPCB verified for v1.0
    [bitcrusher-sh.kicad_sch, bom.csv, designators.csv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]
2025-12-11 Verfied JLCPCB for Brain 1.0
    [audio-cv-out.kicad_sch, bom.csv, brain-core.kicad_pcb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]
2025-12-11 Default patch JLCPCB verified
    [default-patch.kicad_pcb, default-patch.kicad_sch]
2025-12-12 Fixed VCF connector positions
    [bom.csv, designators.csv, positions.csv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]
2025-12-12 Fixed ADSR default connector
    [adsr-vca-core.kicad_pcb, adsr-vca-core.kicad_sch, bom.csv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]
2025-12-12 Locked Utils default connector
    [utils-output-ui.kicad_pcb]
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2025-12-12 Added full BOM to VCO
    [psu-eurorack-8-out-full-bom.csv, psu-moduleur-full-bom.csv, raw-oscillator.kicad_sch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]
2025-12-12 Added full BOM to Mixer module
    [power.kicad_sch, sc-mixer.kicad_sch, sidechain-mixer-core-full-bom.csv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]
2025-12-12 Added VCF full BOM
    [power.kicad_sch, vcf-core-full-bom.csv, vcf-core.kicad_sch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]
2025-12-12 Finished BOM for ADSR
    [adsr-lm324.kicad_sch, adsr-vca-core-full-bom.csv, adsr-vca-core.kicad_sch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]
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2025-12-12 Added default patch BOM
    [default-patch-full-bom.csv, default-patch.kicad_sch]
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2025-12-14 Fixed pot part number bug for Mixer module
    [sidechain-mixer-ui-full-bom.csv, sidechain-mixer-ui.kicad_sch]
2025-12-14 Fixed pot part number bug in ADSR+VCA
    [adsr-vca-ui-full-bom.csv, adsr-vca-ui.kicad_pcb, adsr-vca-ui.kicad_sch]
2025-12-14 Fixed UI component part number bugs
    [brain-ui-full-bom.csv, brain-ui.kicad_sch, utils-output-ui-full-bom.csv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]
2025-12-14 Re-exported all UI board production files after fixing pot bug
    [bom.csv, brain-ui.kicad_pcb, designators.csv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]
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2025-12-16 Updated text on PCB
    [designators.csv, vcf-ui.kicad_pcb]
2025-12-18 Fixed Moduleur PSU Eurorack connector BOM part no.
    ref. https://github.com/shmoergh/moduleur/issues/9
    [psu-moduleur-full-bom.csv, psu.kicad_sch]
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2025-12-20 Updated main output jack part no
    [utils-output-ui-full-bom.csv, utils-output-ui.kicad_pcb, utils-output-ui.kicad_sch]
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2025-12-23 Added helper text on PCB for VCO resistors
    [vco-core.kicad_pcb]
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2025-12-23 Updated VCA resistor help text
    [adsr-vca-ui.kicad_sch]
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2025-12-26 Changed Brain J_DEV header to horizontal
    [bom.csv, brain-core-full-bom.csv, brain-core.kicad_pcb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]
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2025-12-30 Document VCA CV input fix for older boards
    Added a fix for VCA overheating issue for boards ordered before Dec 30, 2025, including detailed instructions and images.
2025-12-30 Fixed missing resistor for VCA CV input
    Boards before this commit missed a 200k resistor on the CV input of the VCA,
    which caused the VCA to be very hot.
    Additionally, we've added a small optional passive LP network to the CV input
    to smoothen sudden changes on the CV input (which can cause very minor pops
    on very short attack times for example).
    [adsr-vca-ui-full-bom.csv, adsr-vca-ui.kicad_pcb, adsr-vca-ui.kicad_sch]
2025-12-30 Updated VCA UI version to v1.1
    This revision contains fix for missing resistor on VCA CV input,
    and adds an optional LP filter for the CV input to avoid small pops
    on sudden CV changes (e.g. very short attacks).
    [adsr-vca-ui.kicad_pcb, bom.csv, designators.csv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]
2025-12-30 Update README for v1.0 UI board fix
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2025-12-30 Added 3d printed fixture files and small changes
    [bosch-10X40.stp, bosch-block-left.step, bosch-block-right.step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]
2025-12-30 fixing screw numbers
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2026-01-08 Updated Brain silkscreen bug
    [brain-ui.kicad_pcb]
2026-01-08 Re-generated all production files
    Nothing changed, but regenerated production files for next batch order.
    [adsr-vca-core.kicad_pcb, adsr-vca-ui.kicad_pcb, adsr-vca-ui.kicad_sch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]
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2026-01-11 Fixed FR4 enclosure panels
    There was an inconsistent behavior on the gerber viewer of JLCPCB. Added a layer of GND to all panels with a plated mounting hole that allows full isolation (Faraday-cage) of the enclosure, to minimize noise.
    [designators.csv, fr4-modular-enclosure-back.kicad_pcb, fr4-modular-enclosure-back.kicad_sch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]
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2026-01-16 Improved LFO LED network
    The LFO LED transistor needed a little feedback bias to make it pulse nicely along with the triangle wave.
    [bom.csv, designators.csv, positions.csv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]
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2026-01-16 Fixed CSV formatting
    [enclosure-bom.csv]
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2026-01-18 Fixed CSV
    [enclosure-bom.csv]
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2026-01-24 Fixed socket to header on mixer UI
    [sidechain-mixer-core.kicad_pcb, sidechain-mixer-core.kicad_sch, sidechain-mixer-ui-full-bom.csv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]
2026-01-24 Updated default pin to DNP in VCF core
    [vcf-core.kicad_pcb, vcf-core.kicad_sch]
2026-01-24 Set ADSR core default patch connector to DNP
    [adsr-vca-core.kicad_pcb, adsr-vca-core.kicad_sch]
2026-01-24 Set Utils core default patch connector to DNP
    [utils-output-core.kicad_pcb, utils-output-core.kicad_sch]
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2026-01-24 Updated Stereo Jack product number on Brain MIDI
    [brain-ui-full-bom.csv, brain-ui.kicad_pcb, brain-ui.kicad_sch]
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2026-02-20 Added protection resistor to pulse out on Brain
    [bom.csv, brain-core.kicad_pcb, designators.csv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]
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2026-02-23 Add FIX LOG section to README.md
    Added a fix log section with important notes regarding PCB revisions and a bug fix for v1.0 UI boards.
2026-02-23 Document LED improvement for LFO in FIXLOG.md
    Added a section detailing an improvement for the LED behavior in the LFO circuit, including symptoms and solutions.
2026-02-23 Update README with fix log and revision warning
    Added a fix log section and a warning about PCB revisions. Removed outdated improvement details for v1.0 UI boards.
2026-02-23 Add FIXLOG for UI board v1.0 pulse input issue
    Document fix for UI board pulse input instability issue.
2026-02-23 Update README with fix log and UI board instructions
    Added a fix log section and updated instructions for users building from earlier PCB revisions. Removed outdated fix information for v1.0 UI boards.
2026-02-23 Revise FIXLOG with new bug fixes and instructions
    Updated FIXLOG to include new fixes for Core and UI boards, detailing symptoms and solutions for known issues.
2026-02-23 Update FIXLOG.md with affected boards and symptoms
    Added affected board details and symptoms for fixes.
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2026-02-23 Revise FIXLOG with new fixes and board details
    Updated the FIXLOG to include new fixes and solutions for known issues in PCB revisions, including details for affected boards and specific solutions.
2026-02-23 Correct references in FIXLOG for Core and UI boards
    Updated the FIXLOG.md to correct references to the Core board and specify the Brain UI board in the solution section.
2026-02-26 Update enclosure BOM with new parts and links
    Added new components and updated existing entries in the enclosure BOM.
    [enclosure-bom.csv]
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2026-03-08 Updated mounting hole H3 on Brain to be grounded
    [adsr-lm324.kicad_sch, adsr-vca-core-full-bom.csv, adsr-vca-core.kicad_pcb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]
2026-03-08 Moduleur Hardware v1.1 update
    PSU v1.1
    - Replaced 1N4001 with 1N5822 Schottky diode for overall better performance (faster switch, less temperature dissipation, better surge behavior, ~0.2V voltage drop)
    - Added 1.5KE36A TVS at DC jack for ESD protection
    VCA v1.3
    - Added test resistors to VCA output and VCA input
    Brain v1.3
    - Added testing resistor and protection diode to pulse output on UI board
    - Updated Mounting Hole H3 to connect to GND so it's not necessary to use wired connection to ground the front and backpanel.
    [adsr-lm324.kicad_sch, adsr-vca-core-full-bom.csv, adsr-vca-core.kicad_pcb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]
2026-03-08 Repositioned a resistor on PSU for better enclosure fit
    [bom.csv, designators.csv, positions.csv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]
2026-03-08 Changed board versioning to 'rev' on VCO and Mixer
    [adsr-lm324.kicad_sch, adsr-vca-core.kicad_sch, audio-cv-in.kicad_sch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]
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2026-03-08 Changed board versioning to 'rev' on Default Patch
    [default-patch.kicad_pcb, default-patch.kicad_sch]
2026-03-08 Silkscreen fixes
    [adsr-vca-core.kicad_pcb, vco-core.kicad_pcb]
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2026-05-13 Fixed VCO schemo and PCB after fckckin KiCAD update
    [positions.csv, power.kicad_sch, raw-oscillator.kicad_sch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]
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2026-05-13 Fixed Mixer Core schemo and PCB after fckckin KiCAD update
    [positions.csv, power.kicad_sch, sc-mixer.kicad_sch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]
2026-05-13 Fixed Mixer UI schemo and PCB after fckckin KiCAD update
    [positions.csv, sidechain-mixer-ui.kicad_pcb, sidechain-mixer-ui.kicad_sch]
2026-05-13 Fixed VCF Core schemo and PCB after fckckin KiCAD update
    [bom.csv, positions.csv, power.kicad_sch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]
2026-05-13 Fixed VCF UI schemo and PCB after fckckin KiCAD update
    [positions.csv, vcf-ui.kicad_pcb, vcf-ui.kicad_sch]
2026-05-13 Fixed VCA Core schemo and PCB after fckckin KiCAD update
    [adsr-lm324.kicad_sch, adsr-vca-core.kicad_pcb, adsr-vca-core.kicad_sch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]
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2026-05-13 Updated SOT-363 footprint to show pin 1 properly
    [sidechain-mixer-core.kicad_pcb, vcf-core.kicad_pcb, vco-core.kicad_pcb]
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2026-05-13 Fixed VCA UI schemo and PCB after fckckin KiCAD update
    [adsr-vca-ui.kicad_pcb, adsr-vca-ui.kicad_sch, positions.csv]
2026-05-13 Fixed Utils Core schemo and PCB after fckckin KiCAD update
    [bitcrusher-sh.kicad_sch, bom.csv, lfo.kicad_sch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]
2026-05-13 Fixed Utils UI schemo and PCB after fckckin KiCAD update
    [positions.csv, utils-output-ui.kicad_pcb, utils-output-ui.kicad_sch]
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2026-05-13 Fixed Utils experimental UI schemo and PCB after fckckin KiCAD update
    [dual-headphone.kicad_sch, positions.csv, utils-output-ui.kicad_pcb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]
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2026-05-13 Fixed Brain Core schemo and PCB after fckckin KiCAD update
    [audio-cv-in.kicad_sch, audio-cv-out.kicad_sch, brain-core.kicad_pcb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]
2026-05-13 Fixed Brain UI schemo and PCB after fckckin KiCAD update
    [brain-ui.kicad_pcb, brain-ui.kicad_sch, leds.kicad_sch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]
2026-05-13 Fixed Default Patch schemo and PCB after fckckin KiCAD update
    [default-patch.kicad_pcb, default-patch.kicad_sch, positions.csv]
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2026-10-27 Fixed main output DC offset
    Problem: C14 was supposed to block DC from the audio input, but DC offset
    was still appearing at the amplifier output.
    Cause: The op-amp input had no connection to ground after C14, leaving
    it floating. When DC was present at the input, the capacitor transferred
    charge to this floating node. Without a path to discharge, the node
    could retain a DC voltage, which was then amplified by the op-amp.
    Solution: Added a 100kΩ resistor (R26) between the op-amp’s non-inverting
    input and ground. This provides a discharge path and keeps the input
    centered at 0V. Together with C14 (10µF), it forms a high-pass filter
    with a cutoff frequency of approximately 0.16Hz, well b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
2026-10-27 Revise FIXLOG for bug fix and improvement details
    Updated FIXLOG.md to reflect a new bug fix and detailed solution for the Utils/Output module. Added information on symptoms, causes, and solutions for the issue with DC coupling.
2026-10-27 Update FIXLOG.md with bug fix details
    Added information about the bug fix for boards ordered after Oct 27, 2026, including a link to the relevant commit.
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
